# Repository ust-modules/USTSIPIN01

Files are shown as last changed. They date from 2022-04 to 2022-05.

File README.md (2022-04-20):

# USTSIPIN01A
It is intended for masurement of cosmic radiation and dosimetry by using Silicon PIN diode sensor.  

> USTSIPIN01A was originally named SPACEDOS01A_PCB01A

Top view on SPACEDOS01A_PCB01B

**The first prototype (without connection of PB0 with R12)**
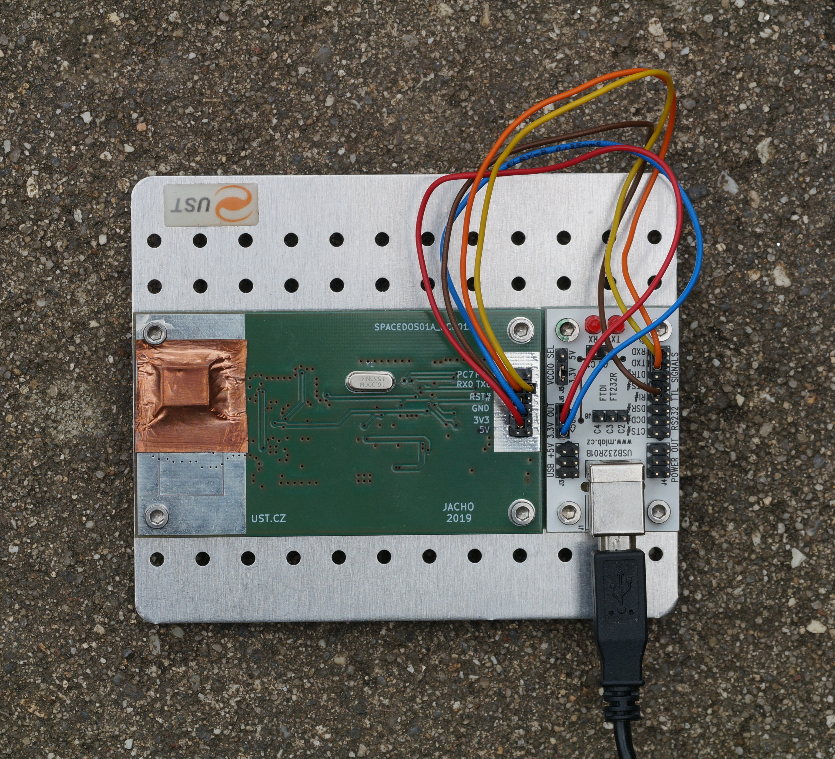
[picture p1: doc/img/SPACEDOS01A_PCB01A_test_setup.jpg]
USTSIPIN01A Test setup


### Technical parameters

* Silicon PIN diode detector with 12.5 mm³ detection volume
* Number of energy channels 250
* Deposited energy range from 200 keV to 12 MeV
* Energy measurement resolution < 50 keV/channel
* Power supply 3.3 V / 3 mA
* Integration time 15 s
* Interface - RS232 TTL
* H x W  x  L - 15mm x 51mm x 91mm

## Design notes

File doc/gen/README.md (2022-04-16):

# PCB

Board size: 90.93x50.29 mm (3.58x1.98 inches)

- This is the size of the rectangle that contains the board
- Thickness: 1.6 mm (63 mils)
- Material: FR4
- Finish: HAL
- Layers: 2
- Copper thickness: 35 µm

Solder mask: TOP / BOTTOM

- Color: Green

Silk screen: TOP / BOTTOM

- Color: White

# Important sizes

Clearance: 0.2 mm (8 mils)

Track width: 0.25 mm (10 mils)

- By design rules: 0.2 mm (8 mils)

Drill: 0.4 mm (16 mils)

- Vias: 0.4 mm (16 mils) [Design: 0.3 mm (12 mils)]
- Pads: 0.76 mm (30 mils)

Via: 0.8/0.4 mm (31/16 mils)

- By design rules: 0.8/0.3 mm (31/12 mils)
- Micro via: no [0.2/0.1 mm (8/4 mils)]
- Burried/blind via: no

Outer Annular Ring: 0.4 mm (16 mils)

- By design rules: 0.64 mm (25 mils)

Eurocircuits class: 4C

# General stats

Components count: (SMD/THT)

- Top: 2/14 (SMD + THT)
- Bottom: 87/8 (SMD + THT)

Defined tracks:

- 0.3 mm (12 mils)
- 0.4 mm (16 mils)
- 0.5 mm (20 mils)
- 0.6 mm (24 mils)
- 0.7 mm (28 mils)
- 0.8 mm (31 mils)

Used tracks:

- 0.25 mm (10 mils) (88) defined: no
- 0.3 mm (12 mils) (3) defined: yes
- 0.4 mm (16 mils) (328) defined: yes
- 0.6 mm (24 mils) (93) defined: yes
- 0.8 mm (31 mils) (60) defined: yes

Defined vias:

Used vias:

- 0.8/0.4 mm (31/16 mils) (Count: 223, Aspect: 2.0 A) defined: no

Holes (excluding vias):

- 0.76 mm (30 mils) (2)
- 0.8 mm (31 mils) (2)
- 0.89 mm (35 mils) (12)
- 3.0 mm (118 mils) (4)

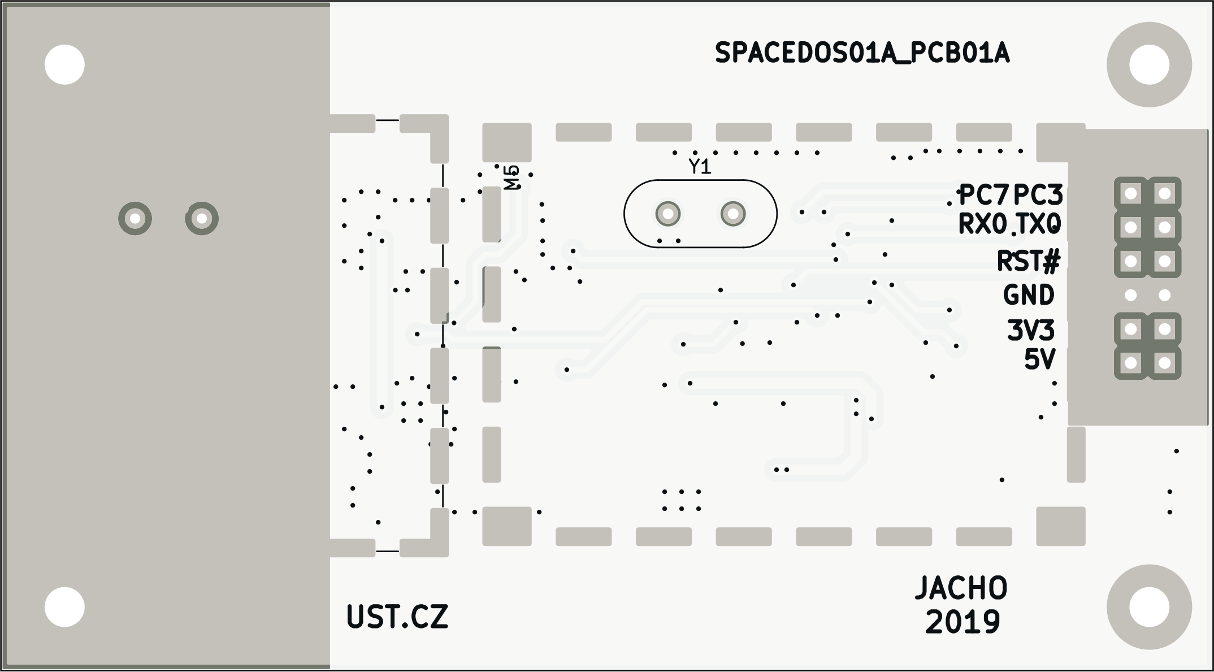
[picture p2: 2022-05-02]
doc/gen/img/USTSIPIN01-top.png

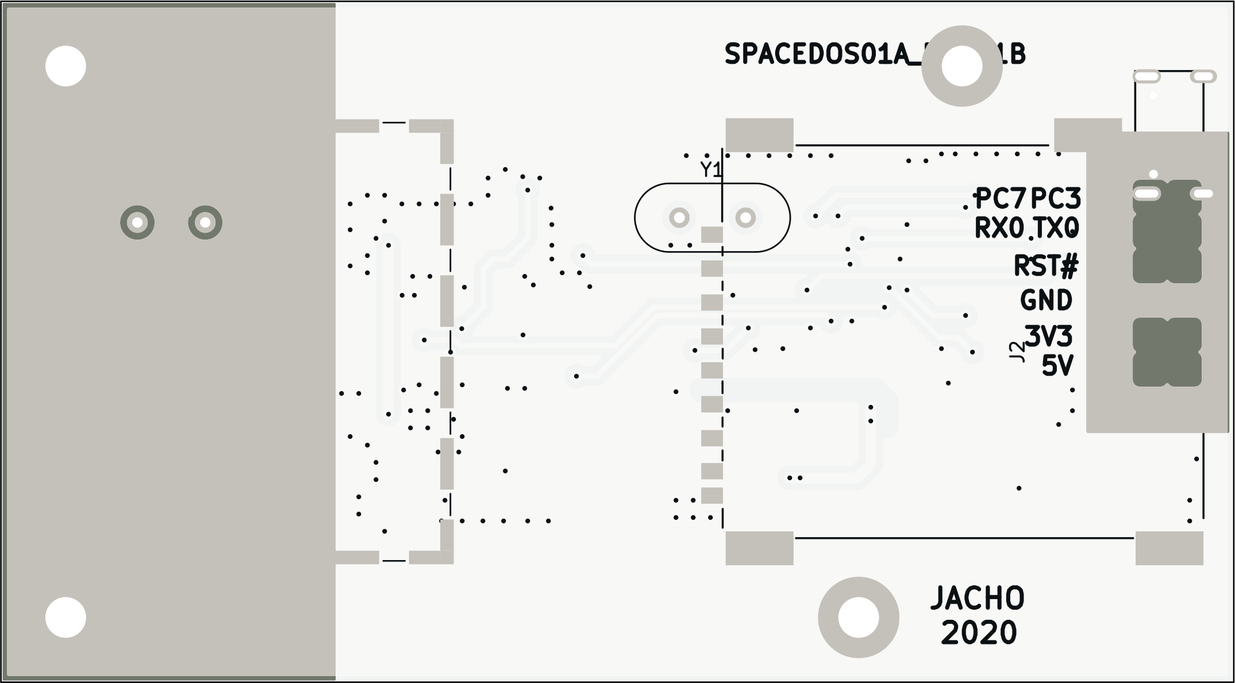
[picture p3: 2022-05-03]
doc/gen/img/USTSIPIN01A-top.png

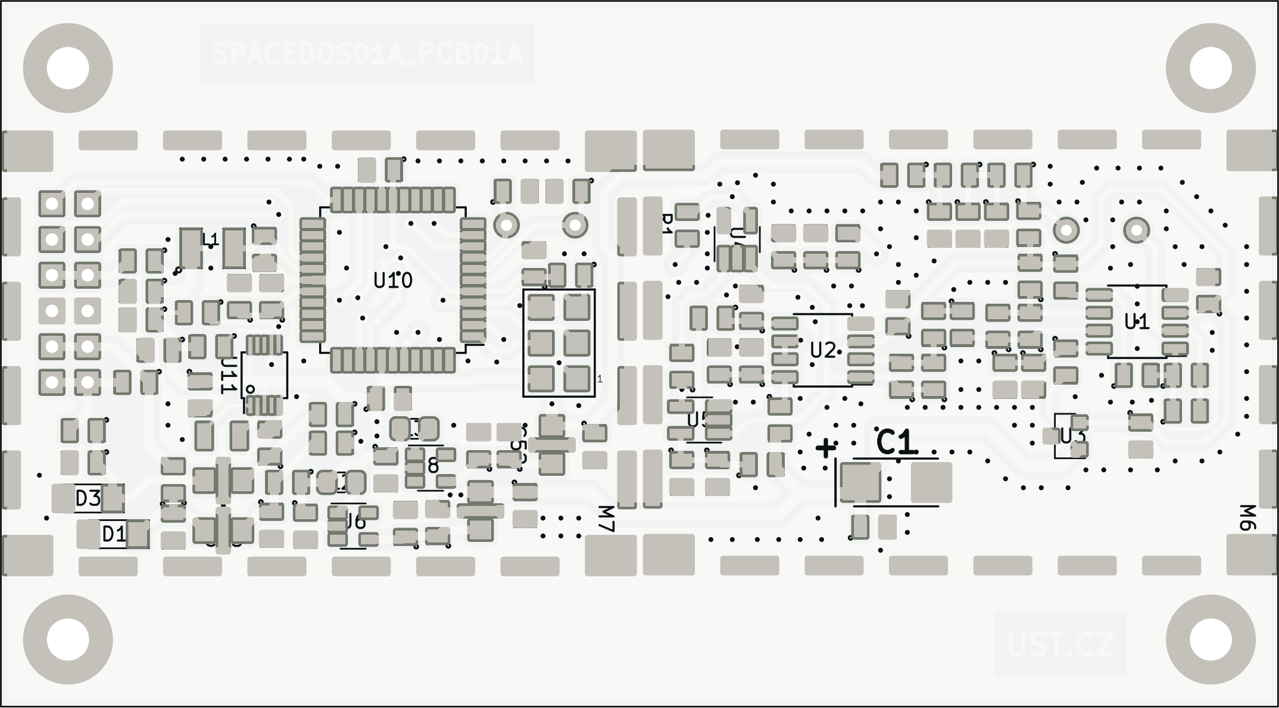
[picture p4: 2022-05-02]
doc/gen/img/USTSIPIN01-bottom.png

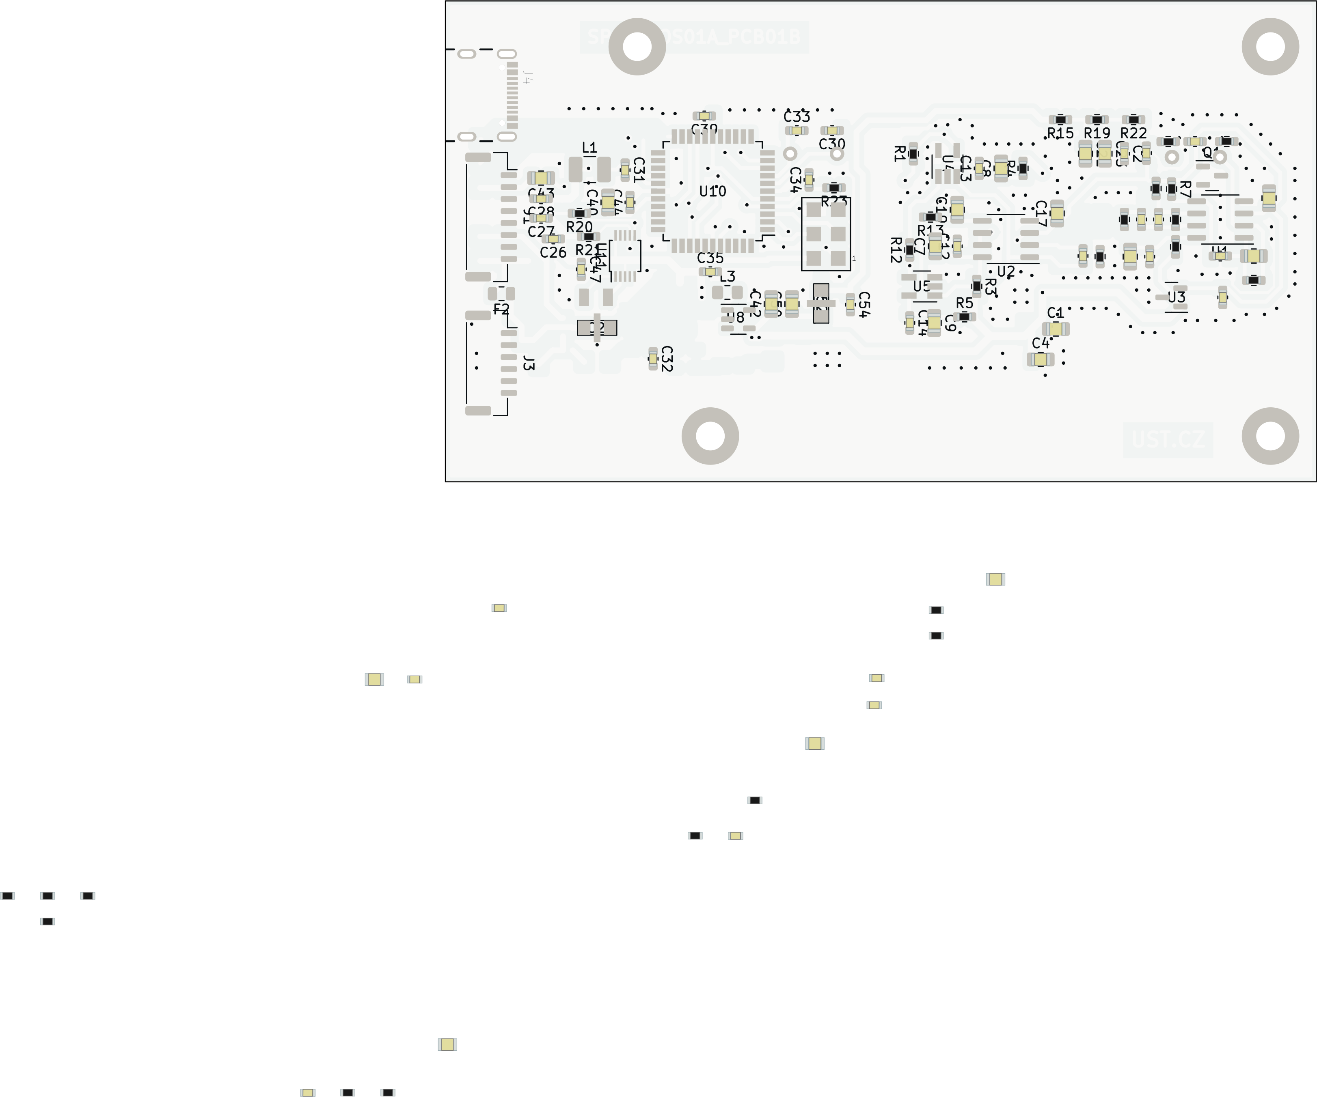
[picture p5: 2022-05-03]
doc/gen/img/USTSIPIN01A-bottom.png

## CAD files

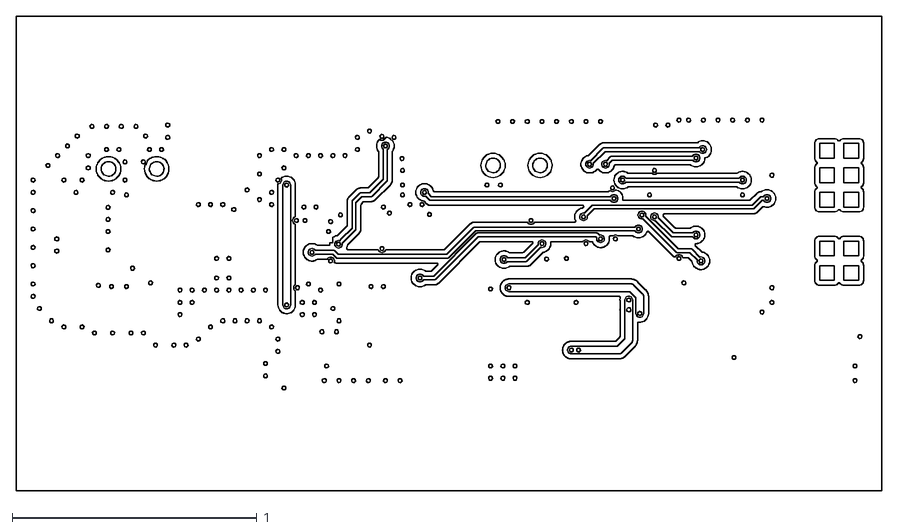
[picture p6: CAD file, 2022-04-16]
doc/gen/dxf/USTSIPIN01-F_Cu.dxf
3.54 x 1.94

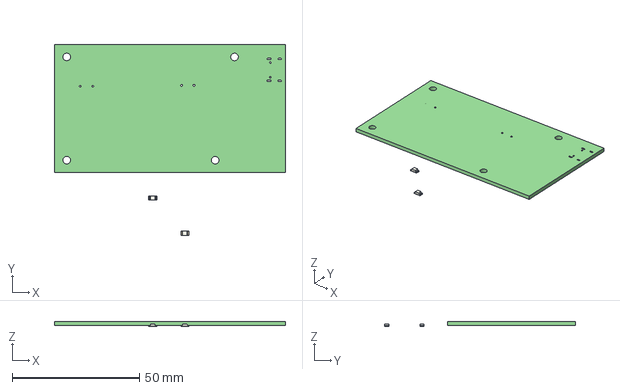
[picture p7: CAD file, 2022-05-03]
doc/gen/USTSIPIN01A.step
90.9 x 75.0 x 2.15 mm
tmpim7qj4tf PCB

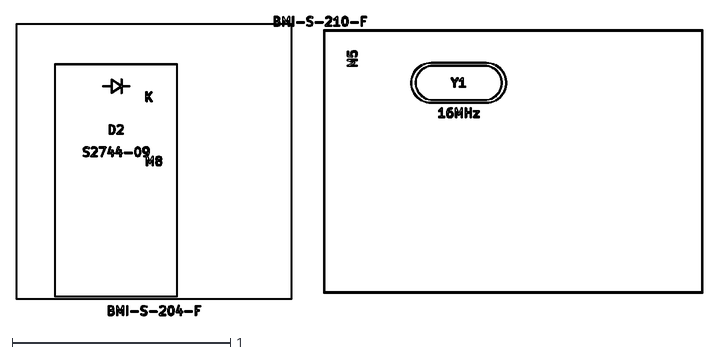
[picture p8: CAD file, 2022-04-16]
doc/gen/dxf/USTSIPIN01-F_Fab.dxf
3.15 x 1.37

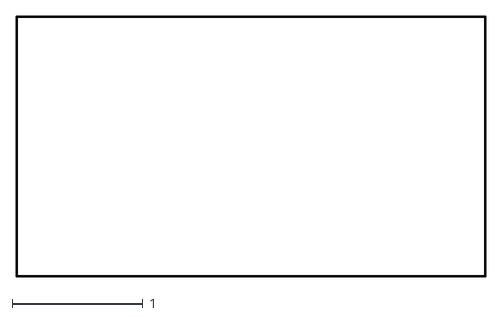
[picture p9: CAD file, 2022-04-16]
doc/gen/dxf/USTSIPIN01-Edge_Cuts.dxf
3.59 x 1.99

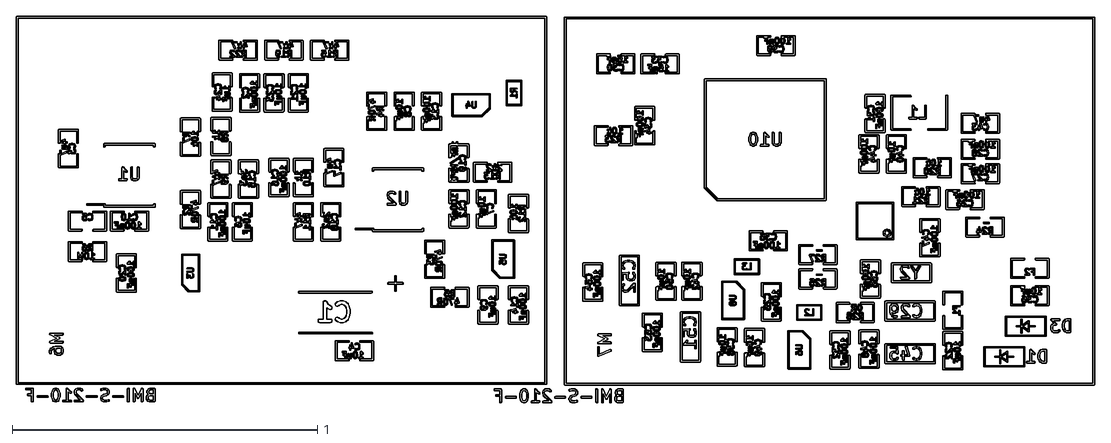
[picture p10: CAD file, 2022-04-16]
doc/gen/dxf/USTSIPIN01-B_Fab.dxf
3.53 x 1.27

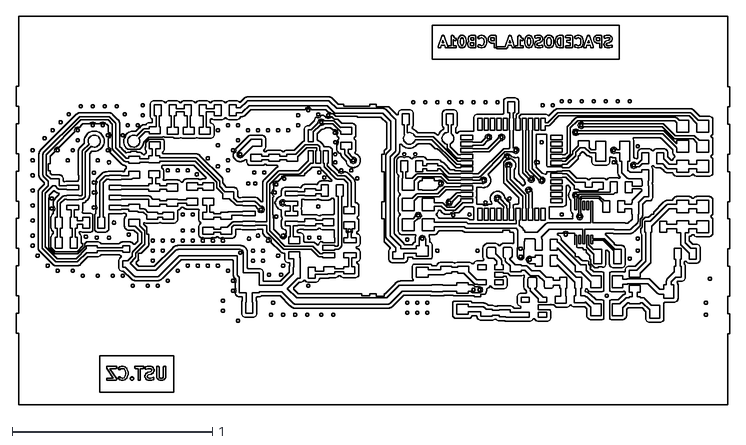
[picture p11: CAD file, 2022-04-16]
doc/gen/dxf/USTSIPIN01-B_Cu.dxf
3.56 x 1.94

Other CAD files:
doc/gen/dxf/USTSIPIN01-B_Mask.dxf
doc/gen/dxf/USTSIPIN01-B_Paste.dxf
doc/gen/dxf/USTSIPIN01-B_Silkscreen.dxf
doc/gen/dxf/USTSIPIN01-F_Mask.dxf
doc/gen/dxf/USTSIPIN01-F_Silkscreen.dxf

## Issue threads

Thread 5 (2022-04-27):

Označení konfigurace detektoru

roman-dvorak, 2022-04-27:
Detektor lze vyrobit ve více různých konfiguracích. Bylo by proto vhodné se dohodnout na nějakém jednotném konceptu značení těchto detektorů.

Jako jedna z variant, která mne napadá je, na desce vyhradit místo, na které se bude lepit vytištěný štítek (z tiskárny na štítky), kdy štítek ponese variabliní informace. Štítek by měl mít jednotný formát.

Informace štítku:
 - Sériové číslo, datum výroby
 - Rozsah energií #4
 - Kalibrace?

Vzhledem na místo na PCB a stinícím krabičkám:
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
By ideální místo bylo okolo hrany PCB, kde je 10 mm (existuje 9 mm široký štítek, znamenalo by to na silksceenu přesunout název modulu někam jinam) nebo přímo na stínící krabičku.

kaklik, 2022-05-03:
Pokud takový štítek bude v lidsky čitelném formátu, tak bude dost velký.  Nebylo by lepší na detektor lepit spíše něco jako seriové číslo a jeho parametry mít uloženy jinde? Například v nějaké databázi.
Stejný princip se už používá i u jiných snímačů viz https://en.wikipedia.org/wiki/IEEE_1451#Transducer_electronic_data_sheet

roman-dvorak, 2022-05-03:
Nemusí být tak velký, aby se to tam nevešlo. Záleží, co vše má být součástí. Mohou tam být poznamenány pouze základní údaje. Tj. třeba 3,4 hodnoty. Zbytek pak někde jinde dle výrobního čísla.

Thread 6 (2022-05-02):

Integrated USB

roman-dvorak, 2022-05-02:
Použitý MCU obsahuje dvě hardwarové UART rozhraní. Jedno rozhraní by se mohlo vyhradit pro USB, které by se používalo pro "přenosné" a "krátkodobé" aplikace, kdy by se zařízení připojovalo k uživatelskému počitači. USB by zároveň sloužilo pro nahrávání firmware pomocí [Obslužné aplikace](https://github.com/UniversalScientificTechnologies/SPACEDOS03/issues/4).

Druhá sériovka by byla užívána pro aplikace, kde by zařízení bylo umístěné někam, kde by byl cizí UART datalogger. Nebo pro aplikace, kde je potřeba data přenášet na větší vzdálenost. Zároveň by to umožňovalo moct změnit firmware/konfiguraci zařízení po USB bez rozpojování zařizení či demontáže.

Díky integraci USB by SPACEDOS03A se stal velmi kompaktním a odolným zařízením. Následně by se pro zařízení mohla vyvinout nějaká tištěná/frézovaná hliníková krabička.

Nepříjemností pro vyřešení tohoto kroku je, že nemáme vyrobený a otestovaný [RS232R02](https://github.com/mlab-modules/USB232R02) převodní, který by se do USTSIPINu mohl zaintegrovat. Zároveň by měl (z pohledu životnosti/odolnosti) nejhorší pouzdro z celého modulu. Převodník však existuje ve variantě [SSOP](https://ftdichip.com/wp-content/uploads/2021/10/DS_FT231X.pdf). Ani jedna varianta není v dnešní době snadno koupitelná.

Potřebné kroky:
- [ ] Ověřit, že vybraný převodník je vhodný
- [ ] Upravit návrh PCB
- [ ] Navrhnout vnější design produktu (krabička, potisk, ..)

kaklik, 2022-05-03:
Tohle issue by podle mého mělo být součástí https://github.com/UniversalScientificTechnologies/SPACEDOS03 nikoliv tohoto detektčního modulu.

roman-dvorak, 2022-05-03:
Nesouhlasím.

roman-dvorak, 2022-05-03:
Nesouhlasím, protože tohle issue řeši integraci přímo do PCB za účelem kompaktnosti a zvětšení user-experience. A ne jako další MLAB modul.

kaklik, 2022-05-03:
> Nesouhlasím, protože tohle issue řeši integraci přímo do PCB za účelem kompaktnosti a zvětšení user-experience. A ne jako další MLAB modul.

Ano, to jsem pochopil. Ale řeší to jako vlastnost toho výslednýho zařízení, Nikoliv jako vlastost detekční části (což bylo původně smyslem tohoto modulu a repozitáře)

roman-dvorak, 2022-05-03:
Má to smysl. Protože SPACEDOS03 může mít další specifika oproti USTSIPIN01. Ať už nějaký způsob montáže (tj. krabička) nebo to může být následně využito v nějakých dalších kompletních celcích, kam se to dá přidat jako submodul. S tím, že to bude mít vlastnost, že to například lze například programovat přes USB.

Já to moc nechápu už třeba jen z důvodu, že jsi mi tvrdil, že použitý procesor má jednu hardwarovou sériovku. A přišel jsem s tím, že by to mohlo mít jako rozhraní i USB. Takže to oproti té tvé původnů představě (s jedním vyvedeným UARTEM) to zůstává stále kompatibilní.

kaklik, 2022-05-03:
> Má to smysl. Protože SPACEDOS03 může mít další specifika oproti USTSIPIN01. Ať už nějaký způsob montáže (tj. krabička) nebo to může být následně využito v nějakých dalších kompletních celcích, kam se to dá přidat jako submodul. S tím, že to bude mít vlastnost, že to například lze například programovat přes USB.
>
> Já to moc nechápu už třeba jen z důvodu, že jsi mi tvrdil, že použitý procesor má jednu hardwarovou sériovku. A přišel jsem s tím, že by to mohlo mít jako rozhraní i USB. Takže to oproti té tvé původnů představě (s jedním vyvedeným UARTEM) to zůstává stále kompatibilní.

Myslel jsem si, že ta druhá seriovka se tam dělá softwarově. Nikoliv že na tom modulu bude pouze jen jedna seriová linka. Dvě tam jsou potřěba z toho důvodu, že je k tomu občas potřěba připojit GPS a zároveň mít připojený nějaký nadřazený logger. Netušil jsem že teď je to vyřešené tak, že i ta druhá UART linka je taky HW (a když to tak je, tak bych to nerad měnil).

roman-dvorak, 2022-05-03:
> Nebo mít zařízení (modul), které má vyvedenou jen čistou seriovku na kterou lze něco připojit bez nějakých dalších "překvapení".

Tak z toho důvodu k tomu také poskytujeme schémata. Aby to nebylo "překvapením" ale aby s tím člověk počital. A prostě to bral jako vlastnost tohoto zařizení, že tam bude 200k pullup.

Navíc druhá sériovka to bude stále splňovat.

> Netušil jsem že teď je to vyřešené tak, že i ta druhá UART linka je taky HW (a když to tak je, tak bych to nerad měnil).
Tak rušit jí rozhodně nechceme.

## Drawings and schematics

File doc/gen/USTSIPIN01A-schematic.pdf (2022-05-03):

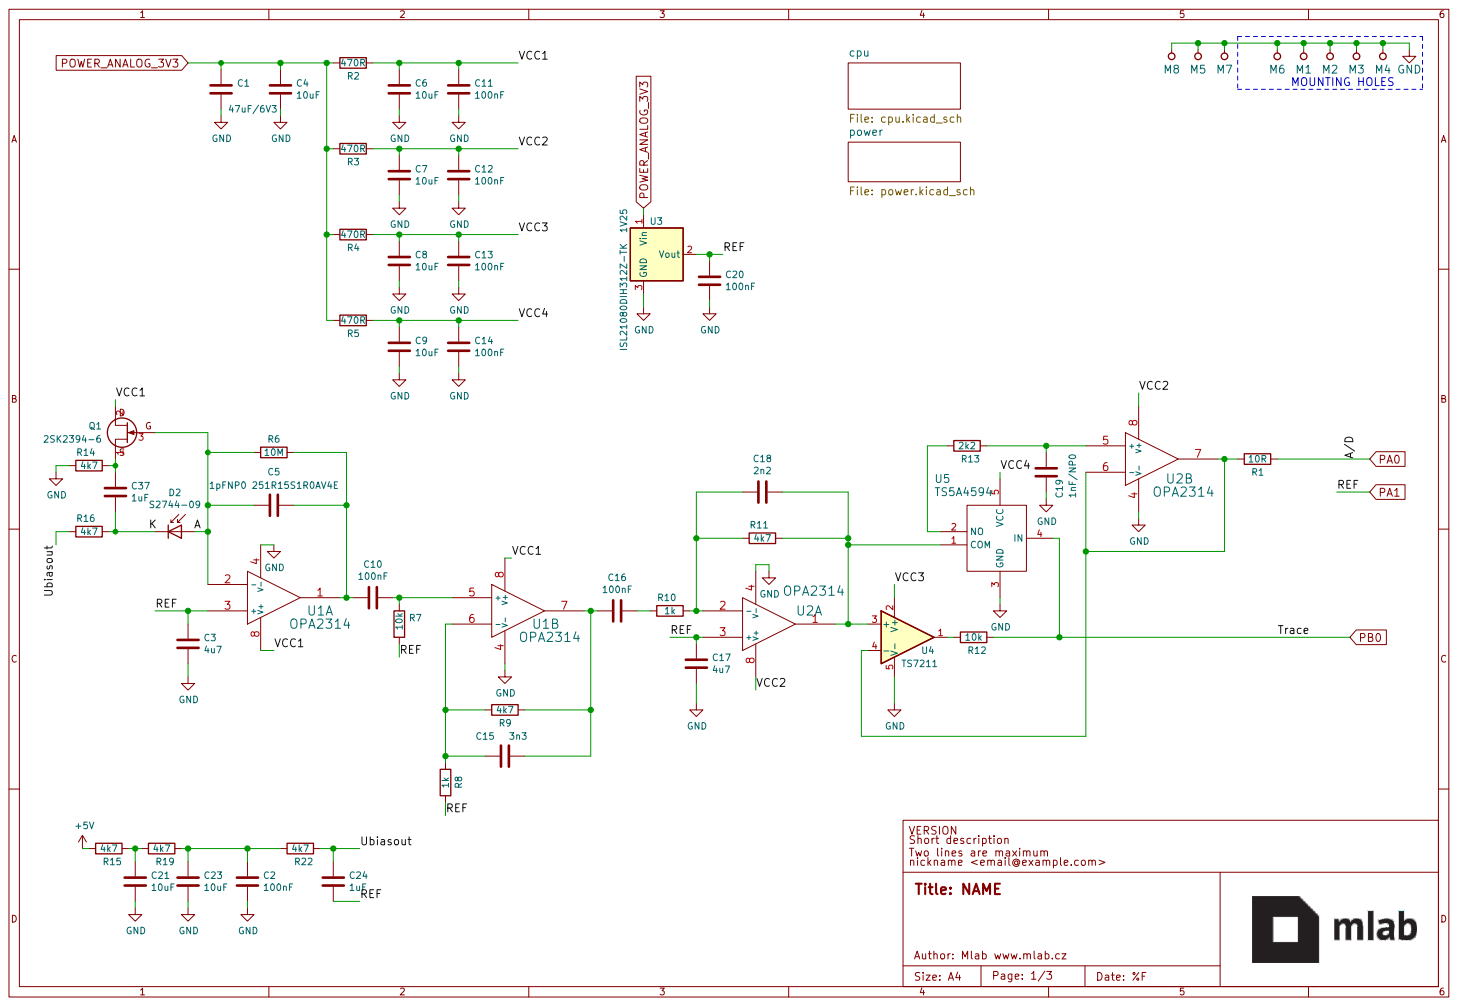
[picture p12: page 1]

VERSION
Short description
nickname <email@example.com>

Two lines are maximum

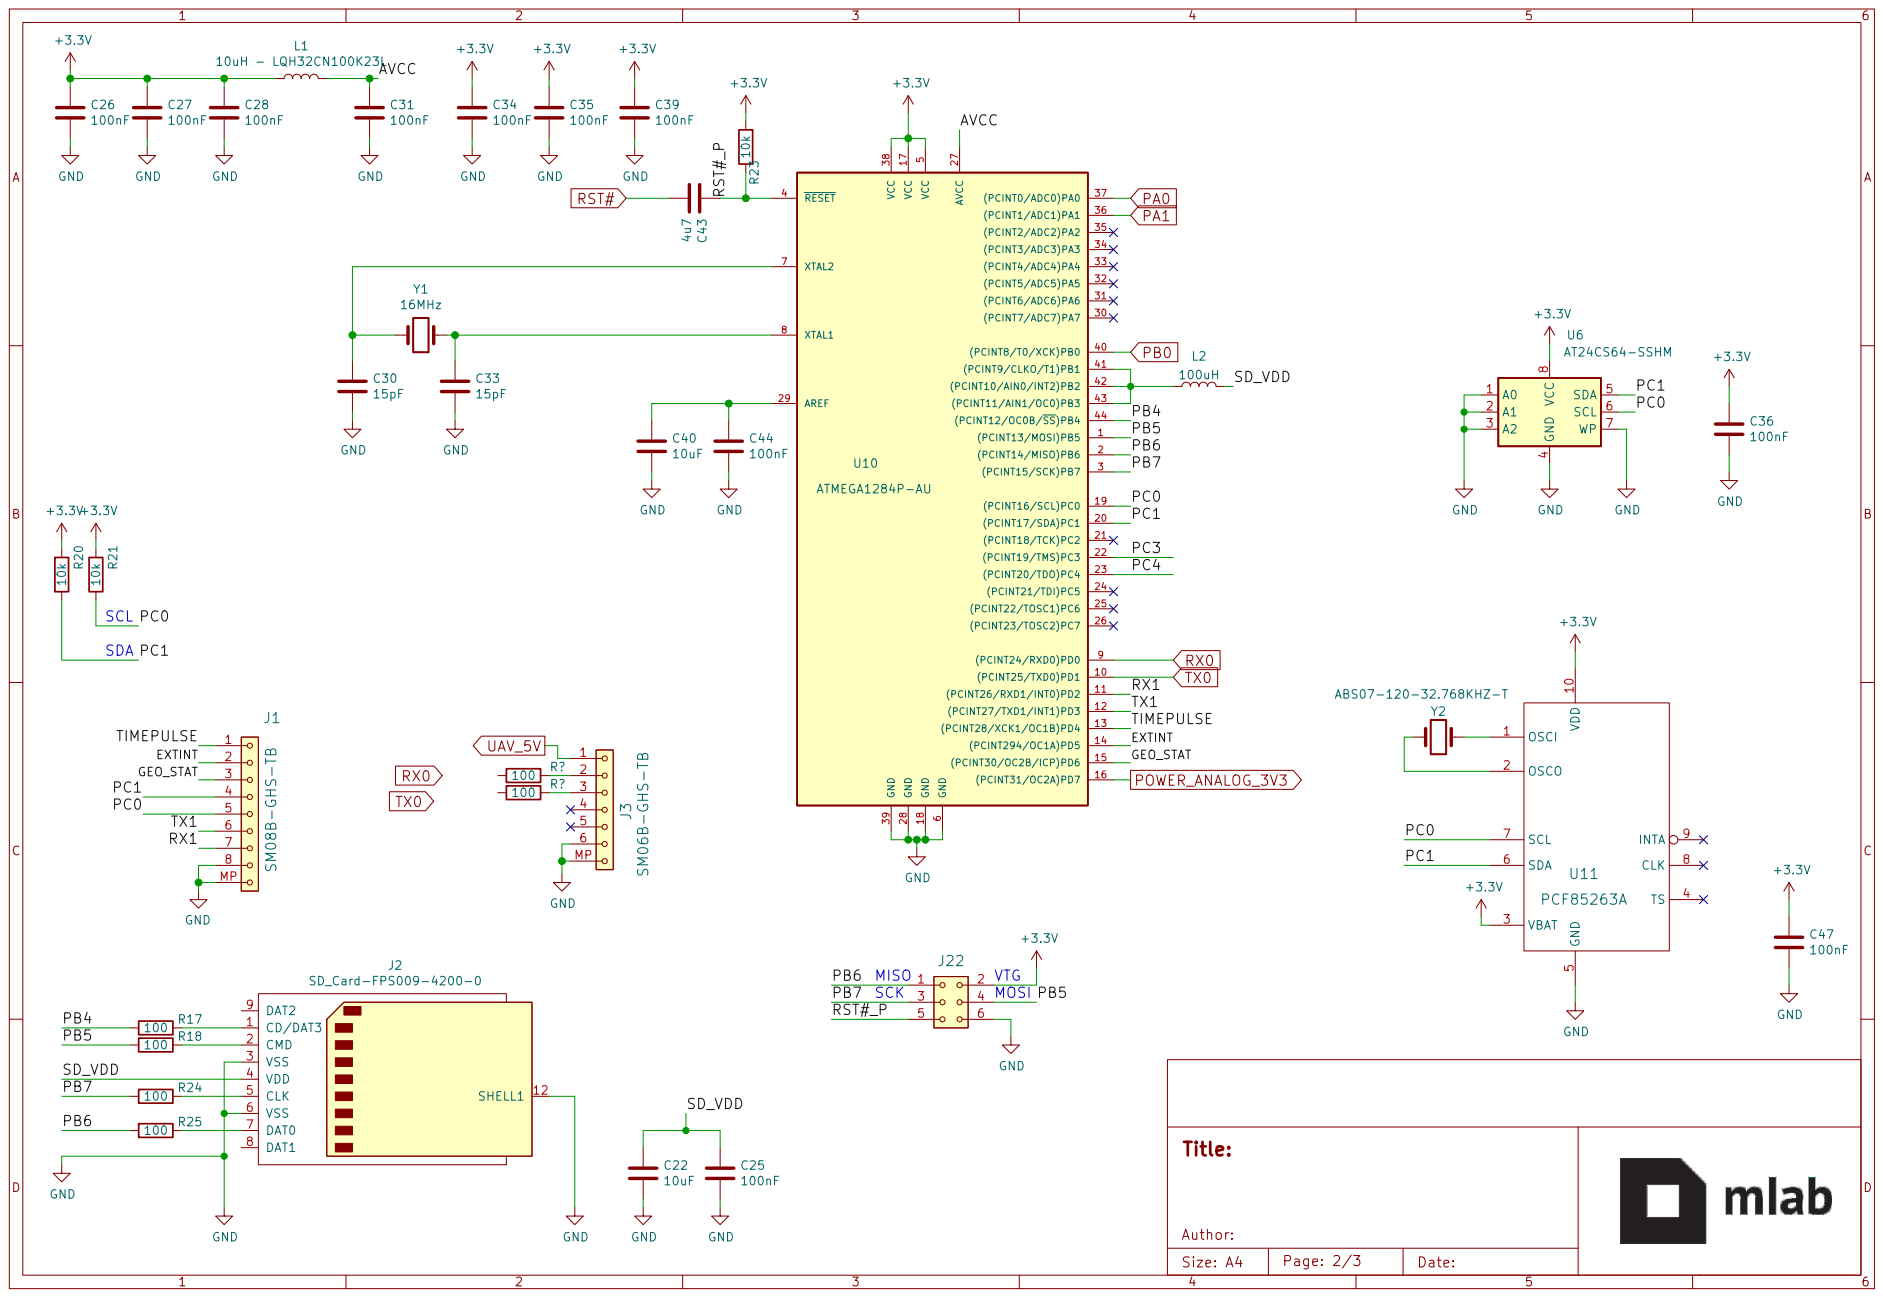
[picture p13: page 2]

4 SDA 5 SCL 6 WP 7 VCC

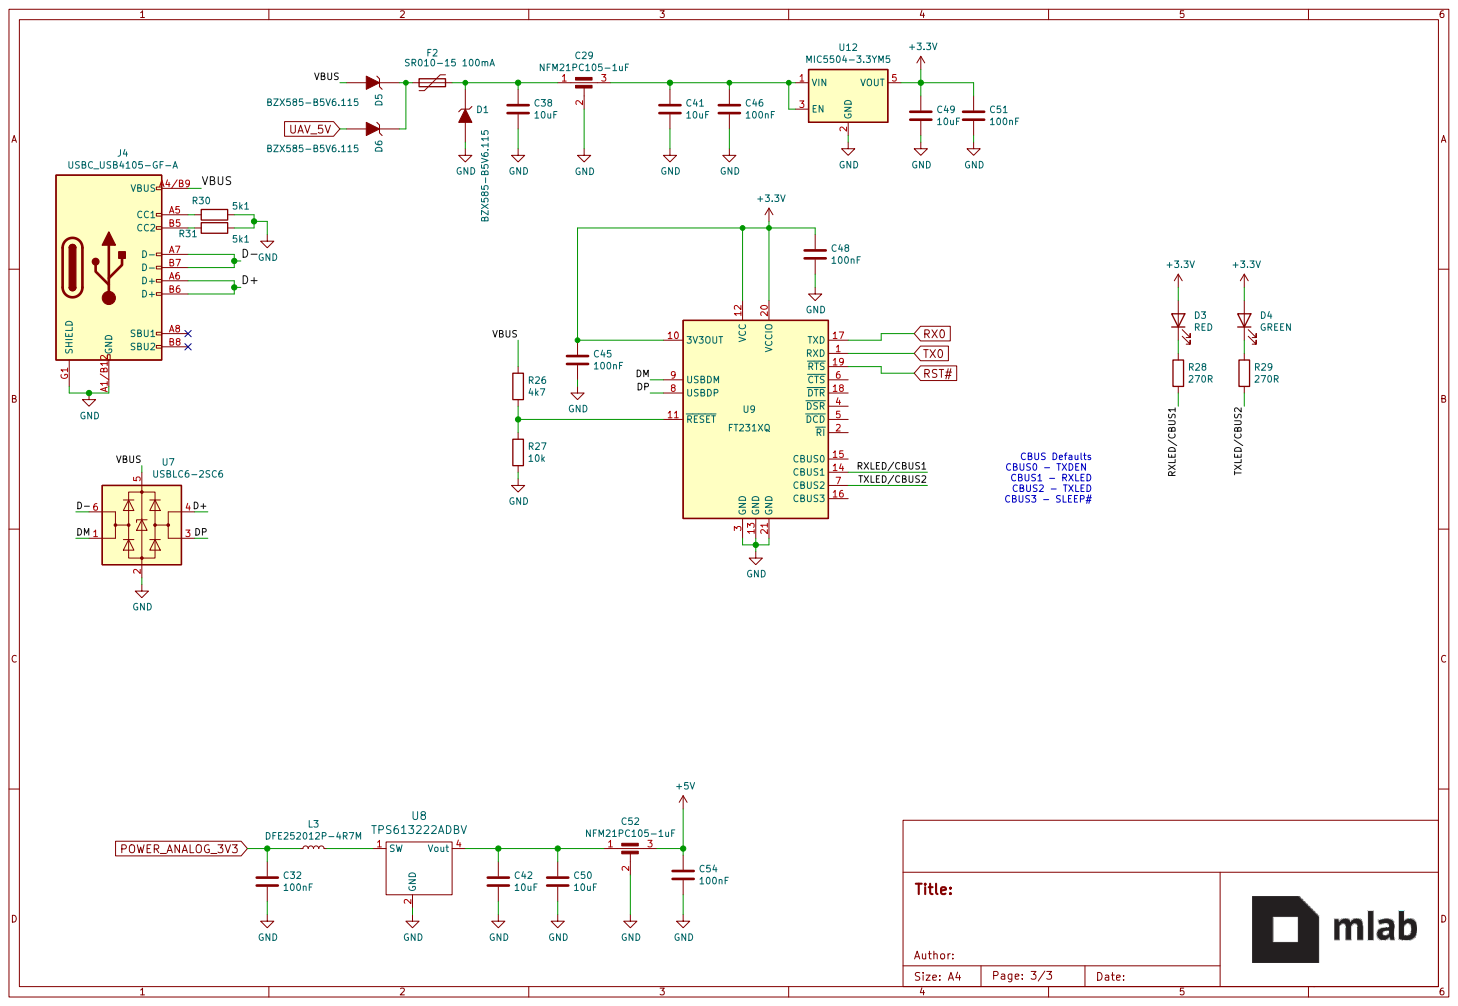
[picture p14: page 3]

3 ~{DSR} 4 ~{DCD} 5 ~{CTS} 6 CBUS2 7 USBDP 8 USBDM 9 U9 FT231XQ

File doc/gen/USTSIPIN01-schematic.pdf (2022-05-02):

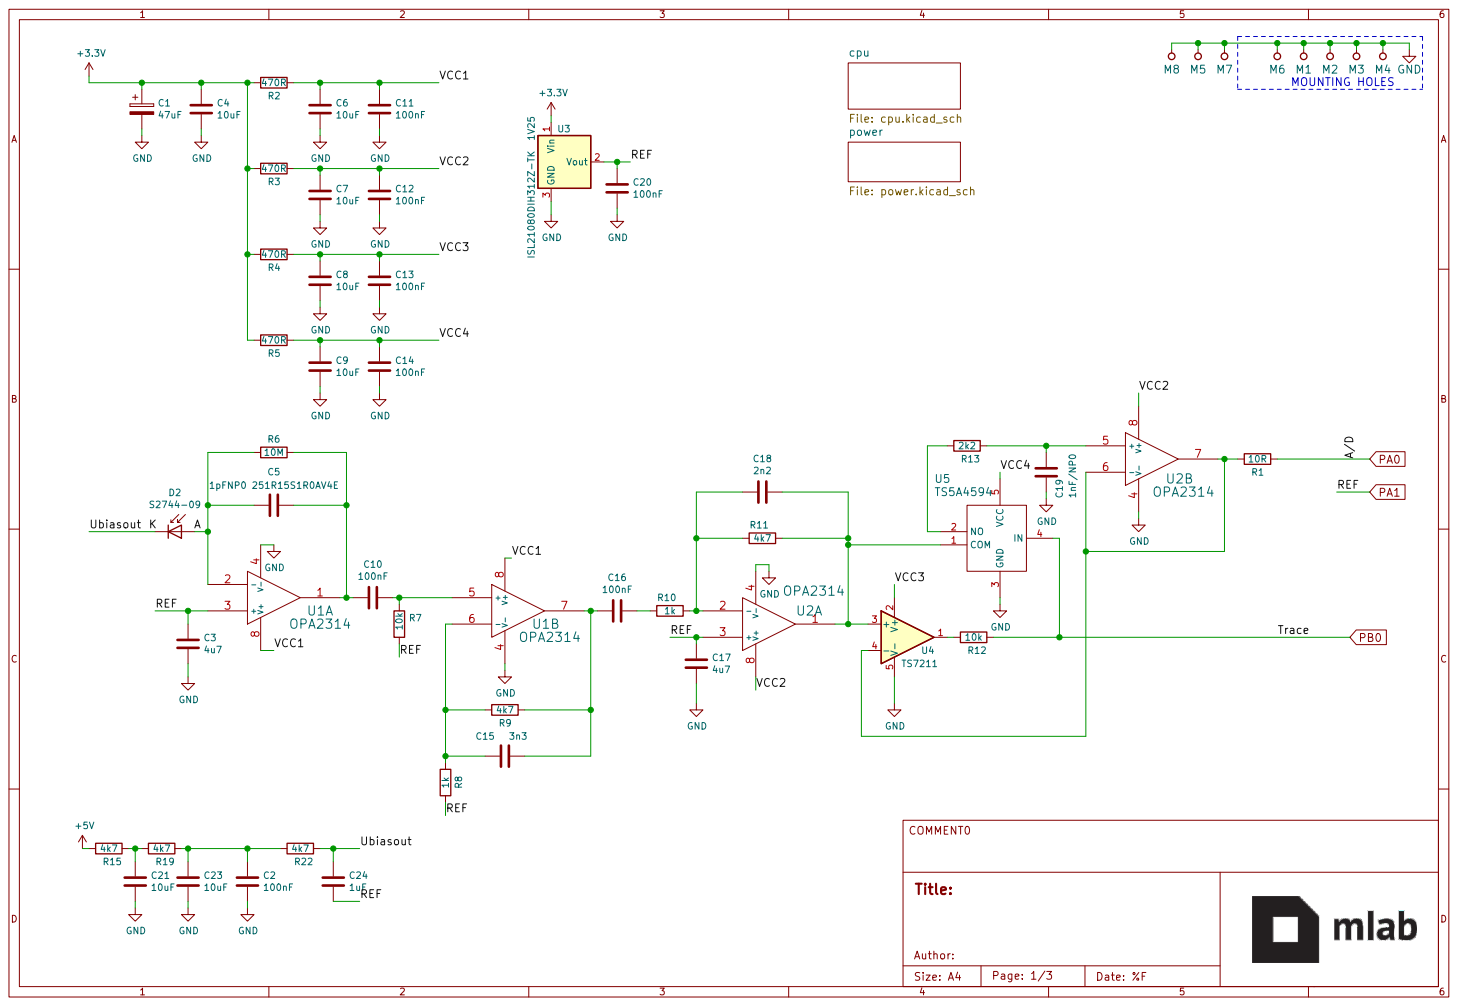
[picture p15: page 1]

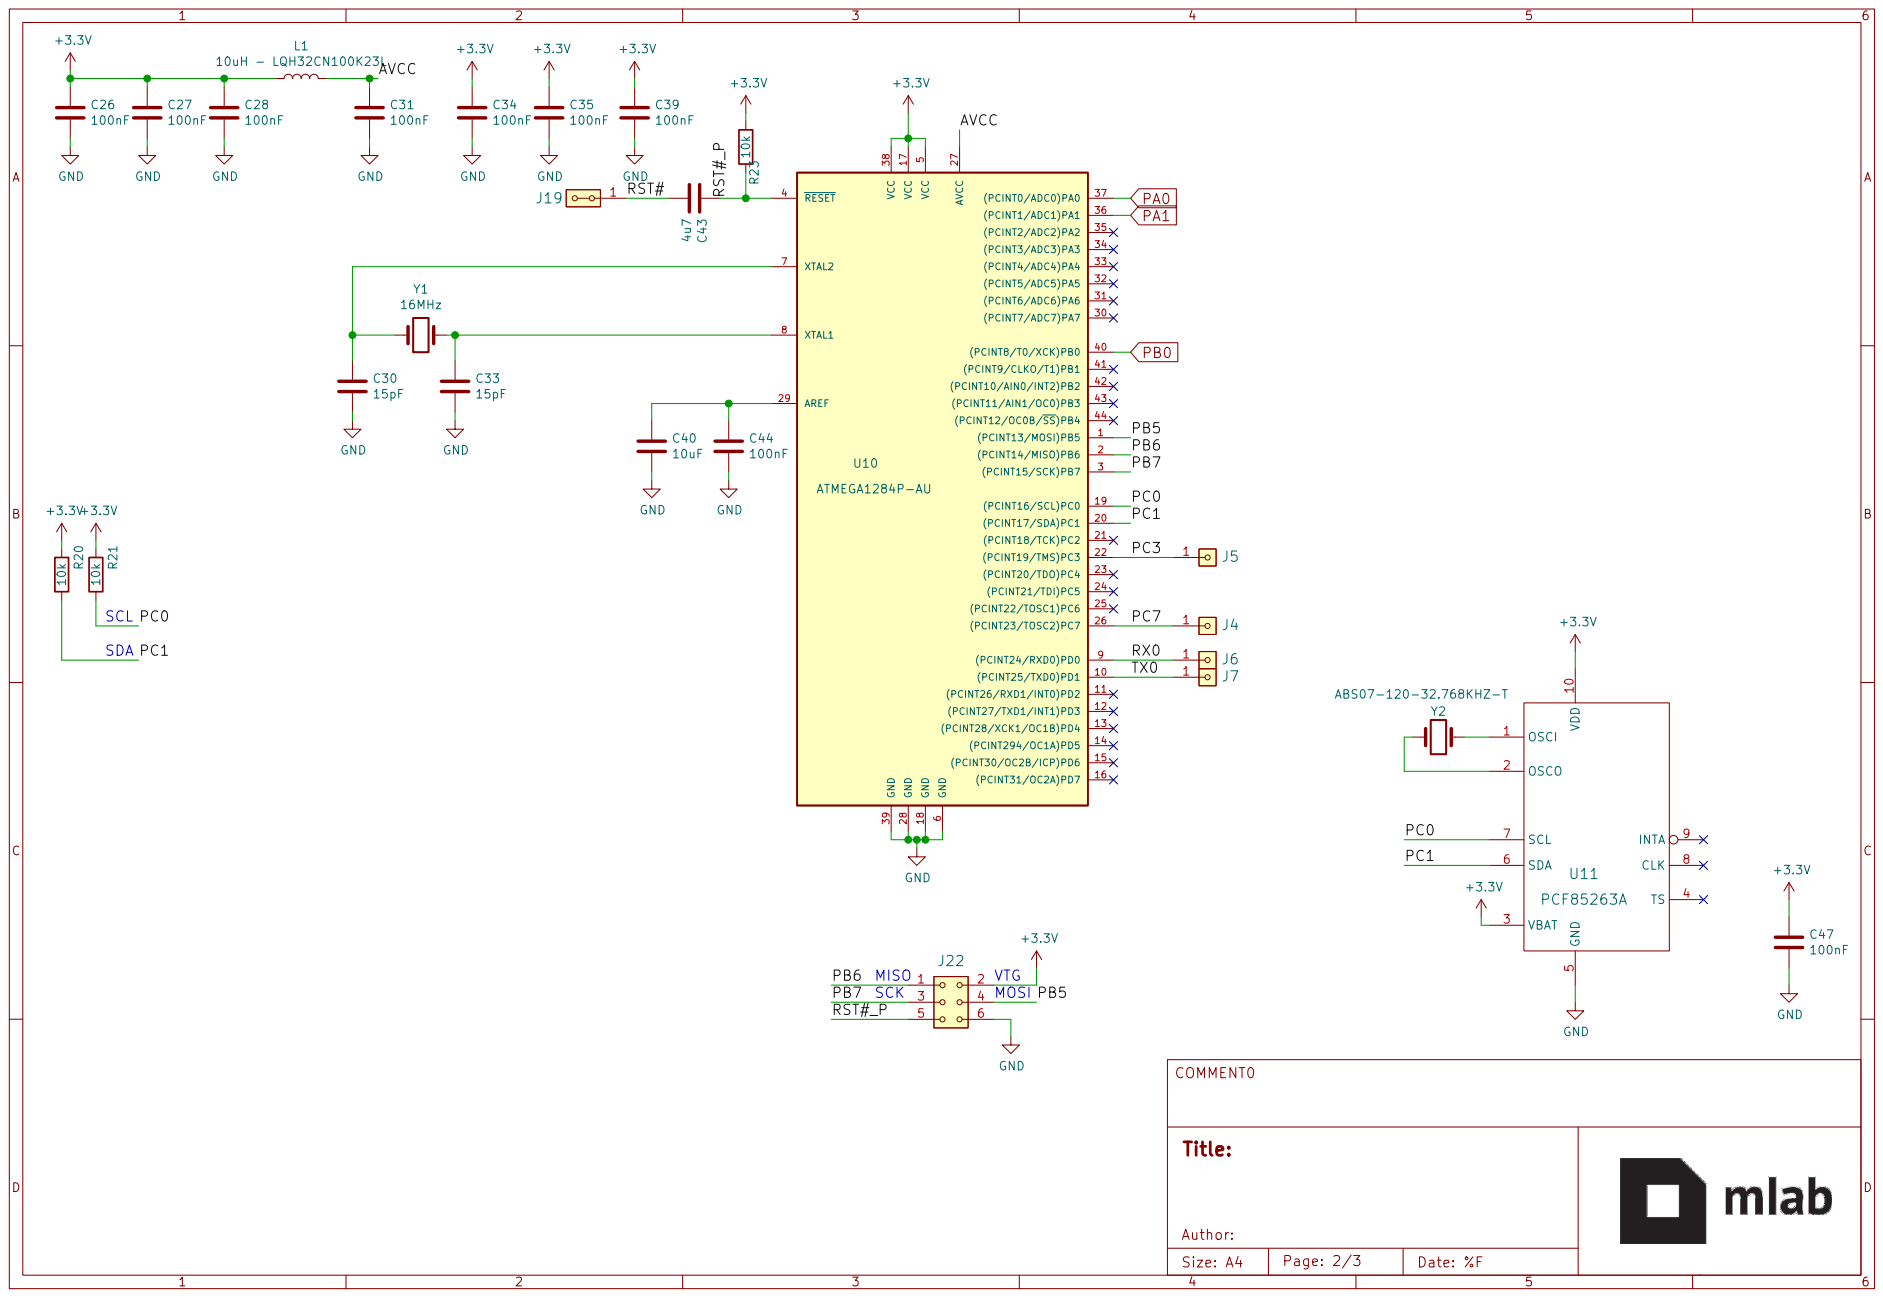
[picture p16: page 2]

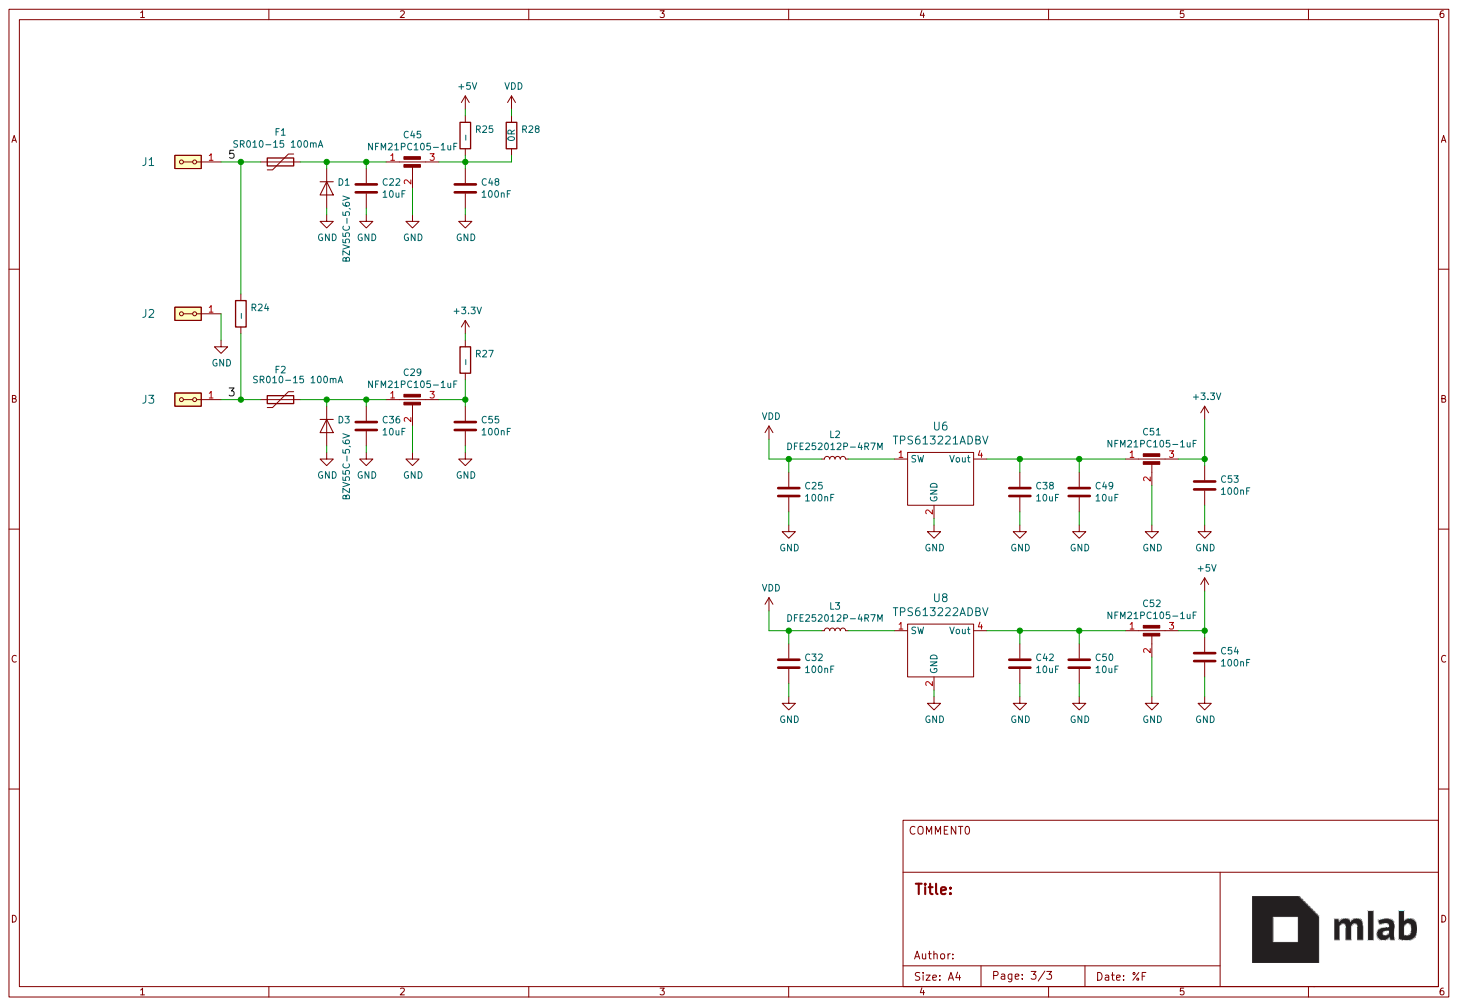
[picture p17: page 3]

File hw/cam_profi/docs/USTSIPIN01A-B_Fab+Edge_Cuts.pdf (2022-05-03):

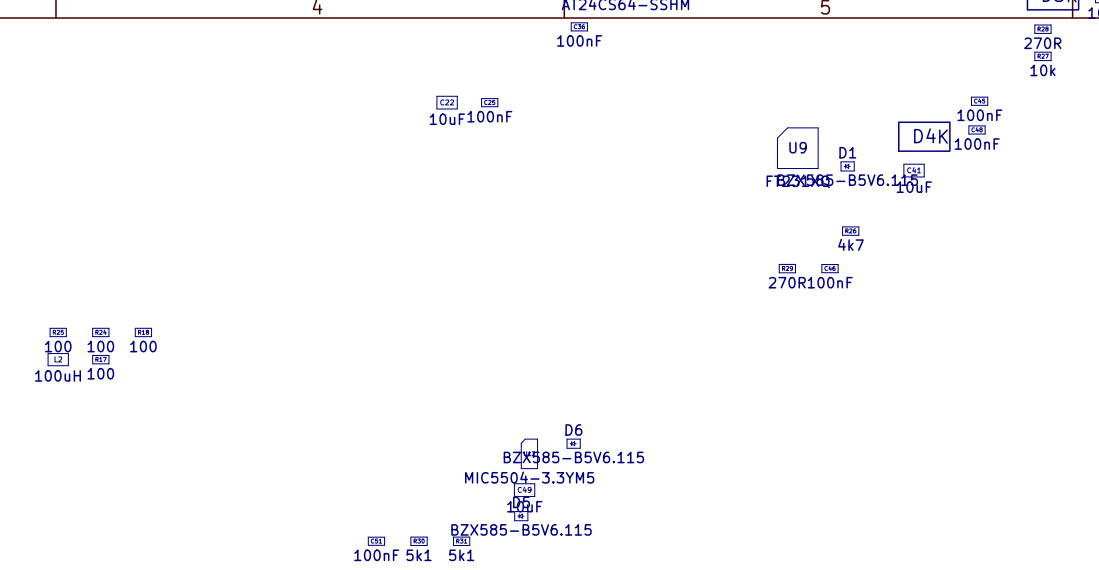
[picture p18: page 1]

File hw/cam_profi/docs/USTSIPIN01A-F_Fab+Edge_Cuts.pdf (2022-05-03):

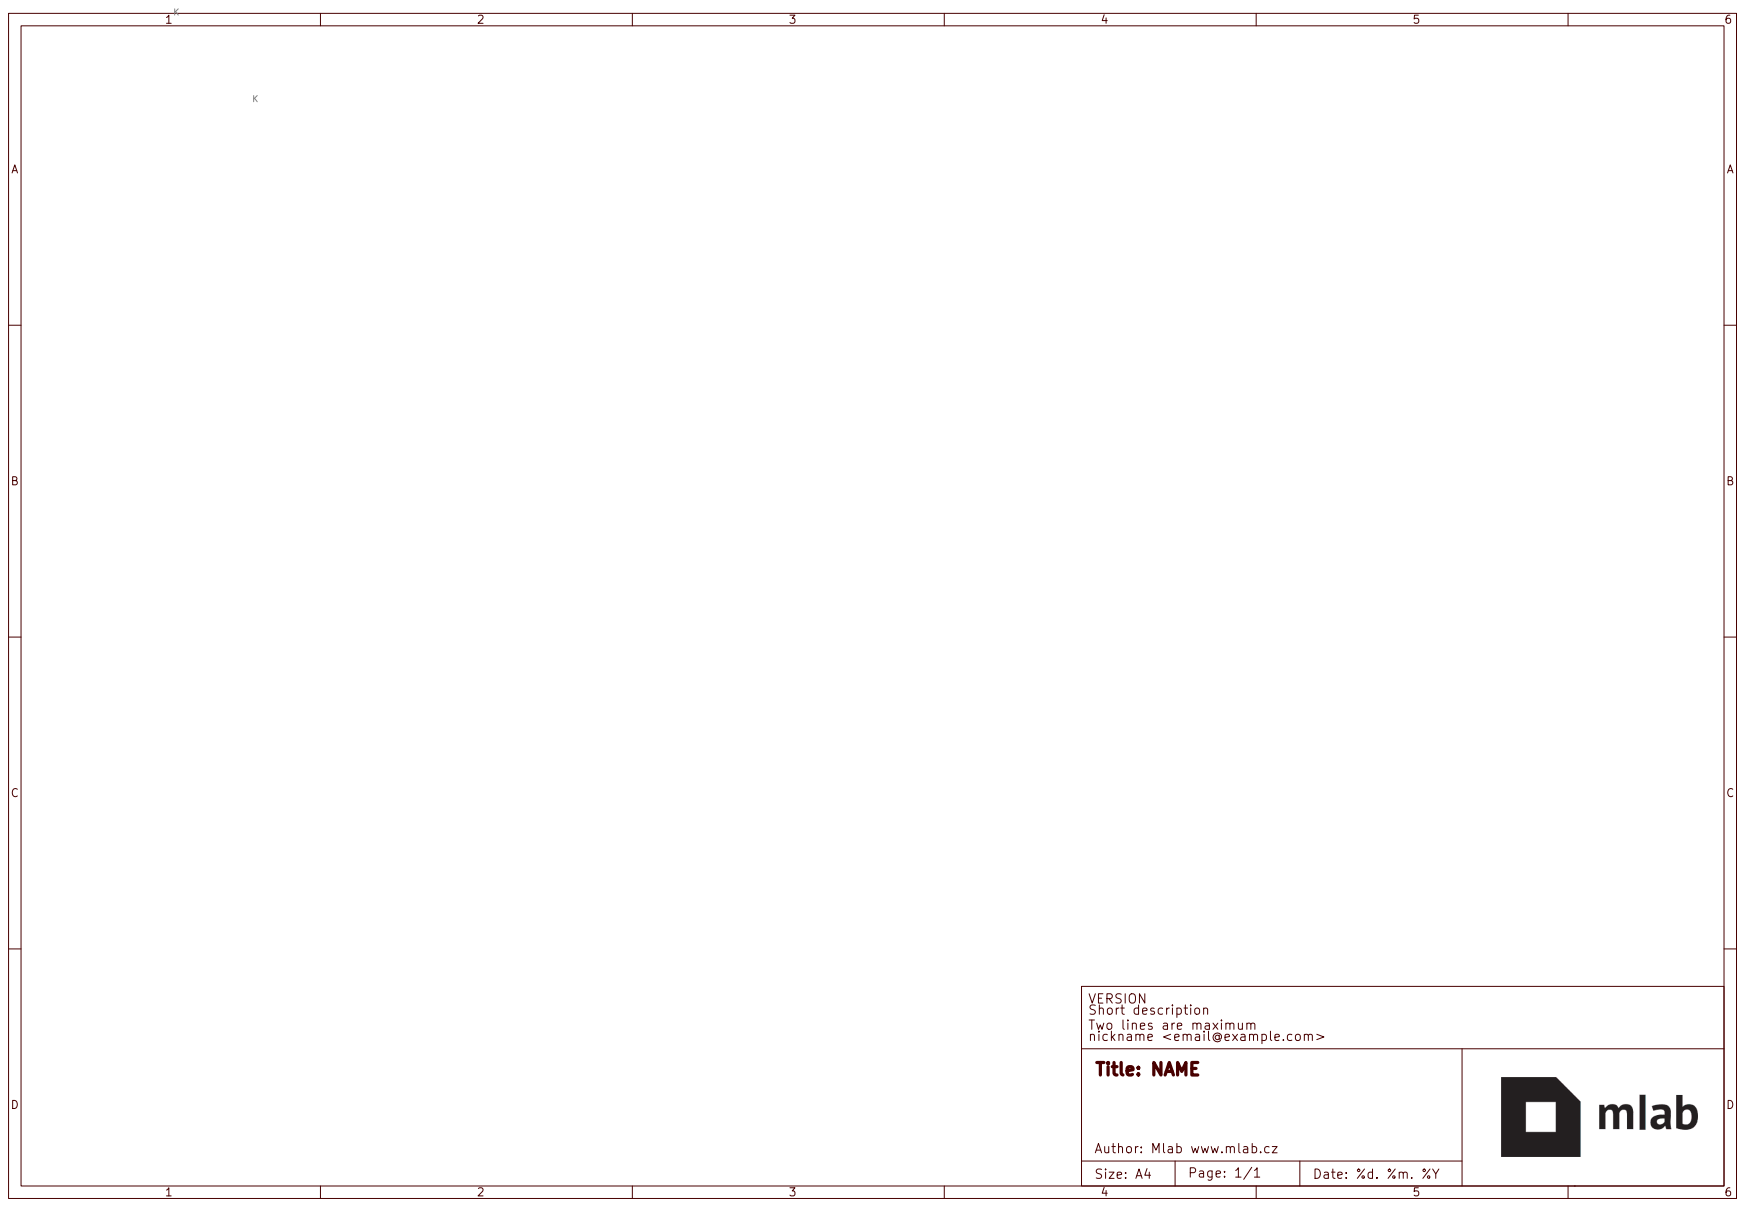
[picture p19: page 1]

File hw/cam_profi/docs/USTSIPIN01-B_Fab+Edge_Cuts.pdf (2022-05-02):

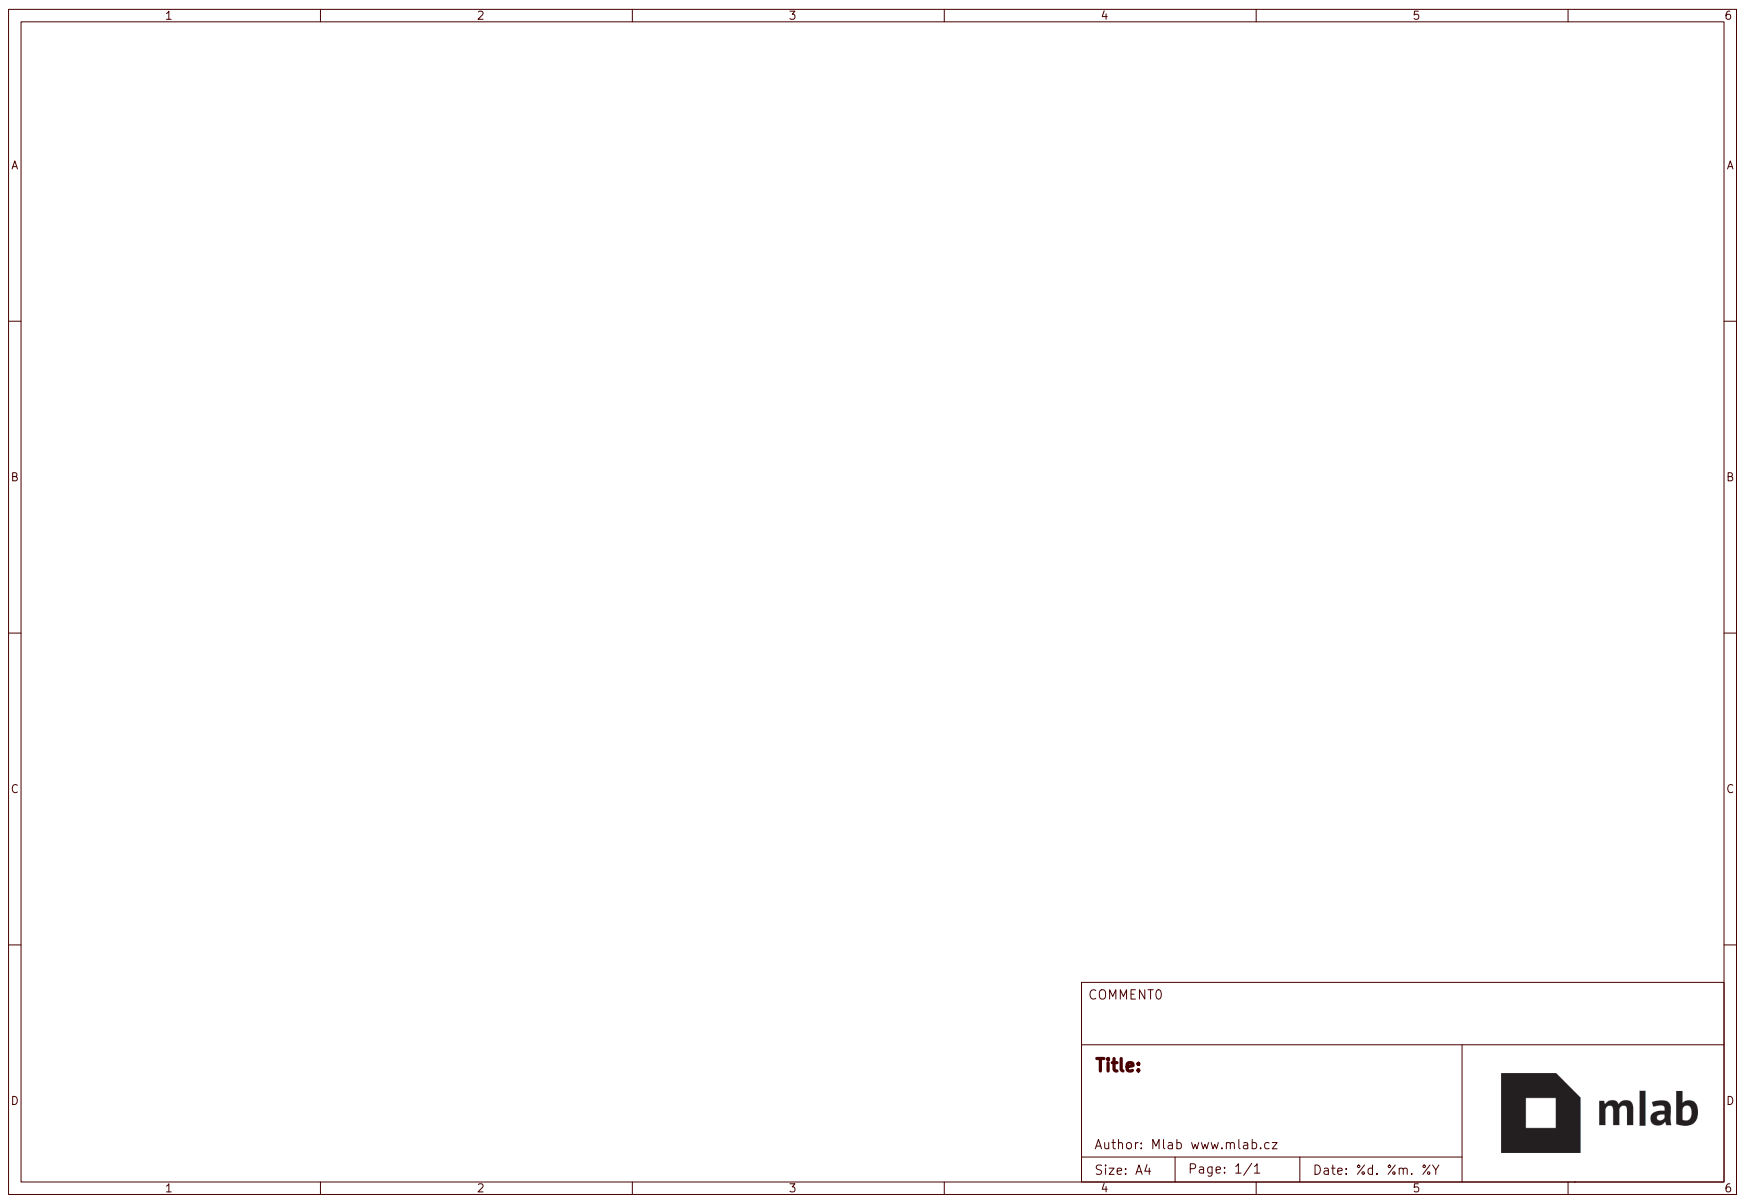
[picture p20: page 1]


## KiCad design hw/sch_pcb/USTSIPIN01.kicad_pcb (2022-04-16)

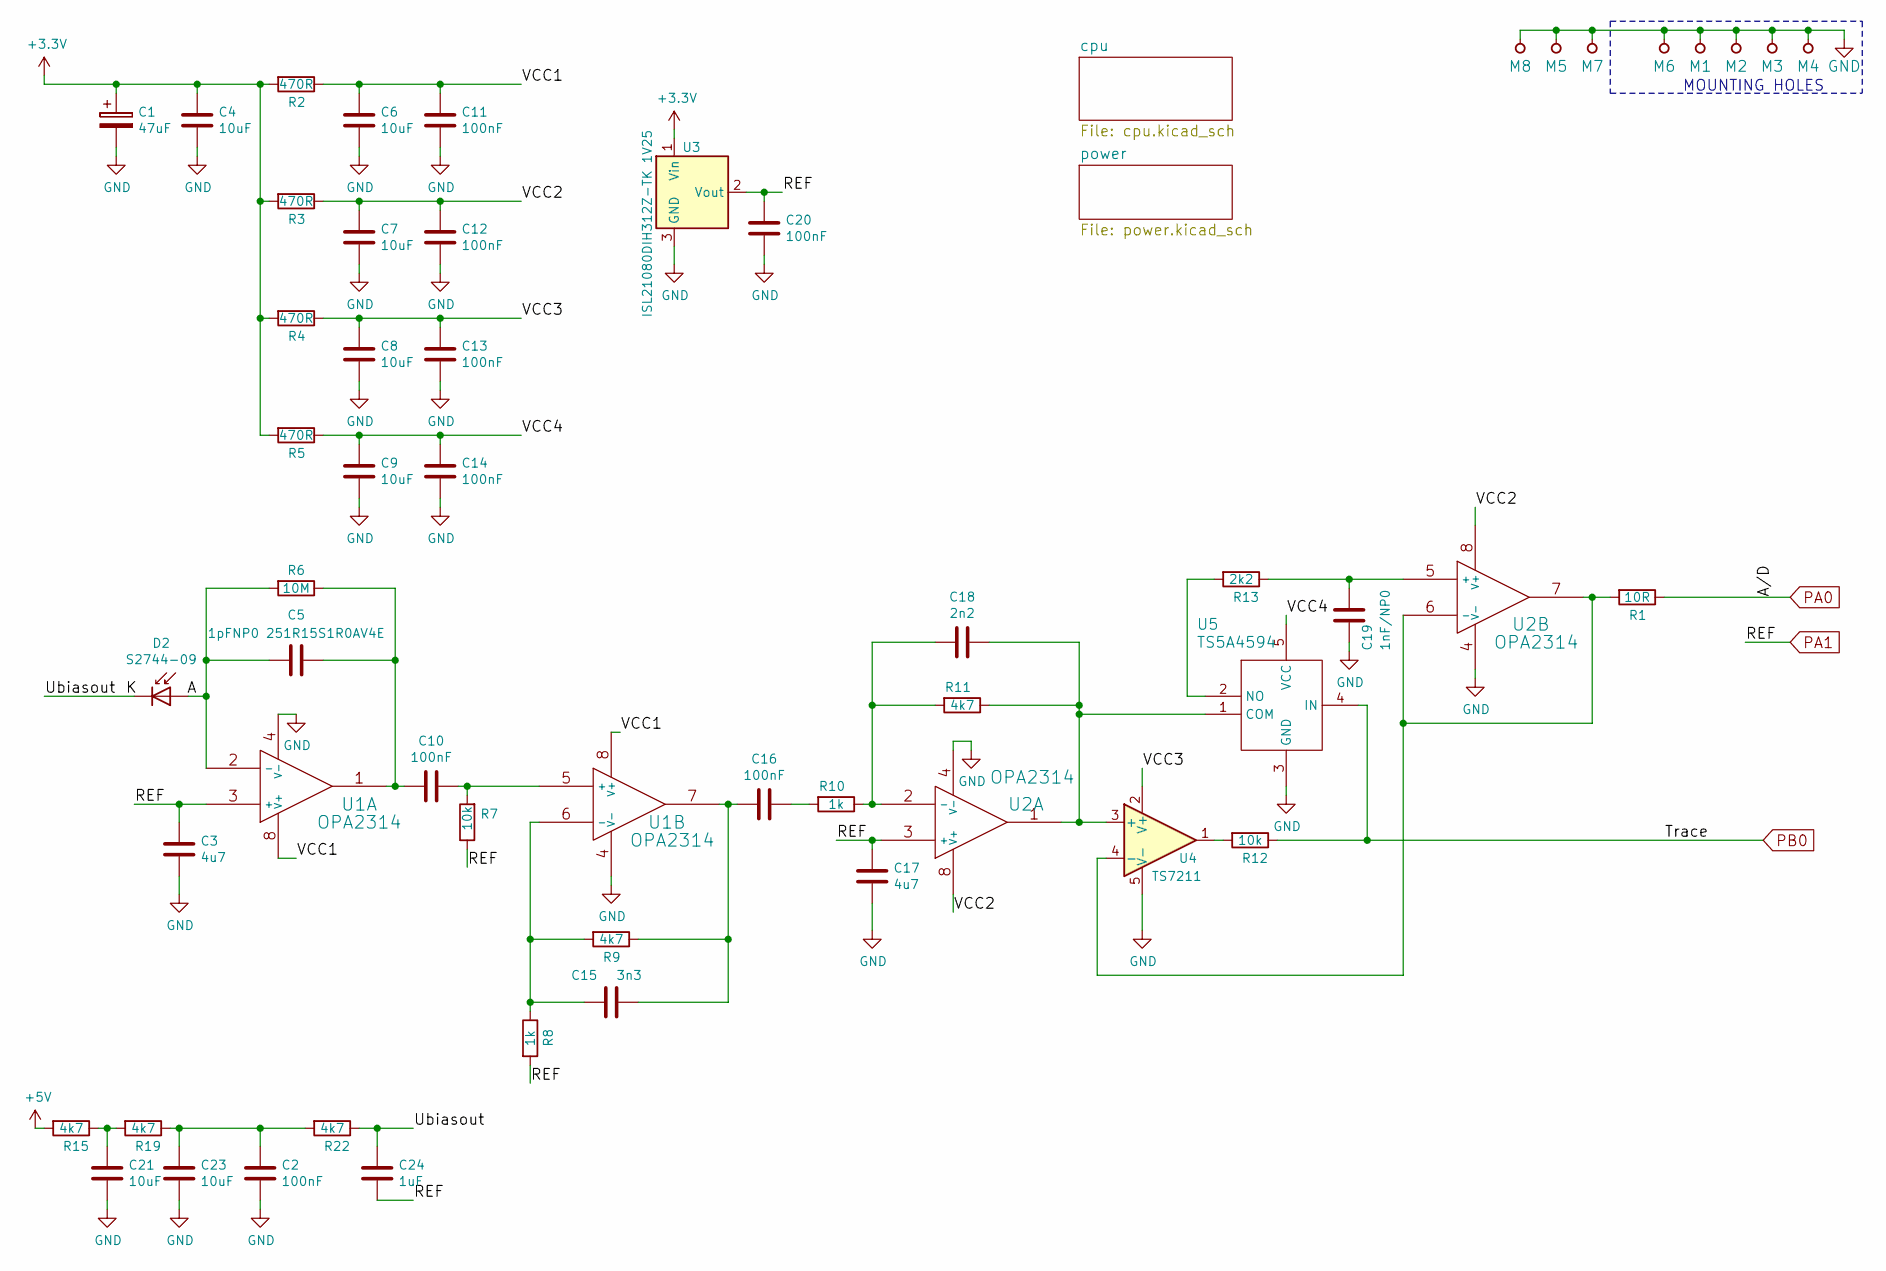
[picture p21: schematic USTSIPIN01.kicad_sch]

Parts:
C1: 47uF; TantalC_SizeC_Reflow
C2, C10, C11, C12, C13, C14, C16, C20: 100nF; SMD-0805
C3, C17: 4u7; SMD-0805
C4, C6, C7, C8, C9, C21, C23: 10uF; SMD-0805
C5: 1pFNP0 251R15S1R0AV4E; SMD-0805
C15: 3n3; SMD-0805
C18: 2n2; SMD-0805
C19: 1nF/NP0; SMD-0805
C24: 1uF; SMD-0805
D2: S2744-09; HAMAMATSU_S2744-09
M1, M2, M3, M4: HOLE; MountingHole_3mm
M5, M6, M7: BMI-S-210-F
M8: BMI-S-204-F; Laird_Technologies_BMI-S-204-F_32.00x32.00mm
R1: 10R; SMD-0805
R2, R3, R4, R5: 470R; SMD-0805
R6: 10M; SMD-0805
R7, R12: 10k; SMD-0805
R8, R10: 1k; SMD-0805
R9, R11, R15, R19, R22: 4k7; SMD-0805
R13: 2k2; SMD-0805
U1, U2: OPA2314; SOIC-8_3.9x4.9mm_Pitch1.27mm
U3: ISL21080DIH312Z-TK 1V25; SOT-23
U4: TS7211; SOT-23-5_HandSoldering
U5: TS5A4594; SOT-23-5_HandSoldering

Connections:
+3V3: C1.1, C4.1, R2.2, R3.2, R4.2, R5.2, U3.1 (Vin); also elsewhere on the board
+5V: R15.2; also elsewhere on the board
/A: C5.2, D2.2 (A), R6.2, U1.2 (-)
/K: C24.1, D2.1 (K), R22.1
/VCC1: C6.1, C11.1, R2.1, U1.8 (V+)
/VCC2: C7.1, C12.1, R3.1, U2.8 (V+)
/VCC3: C8.1, C13.1, R4.1, U4.2 (V+)
/VCC4: C9.1, C14.1, R5.1, U5.5 (VCC)
GND: C1.2, C2.2, C3.2, C4.2, C6.2, C7.2, C8.2, C9.2, C11.2, C12.2, C13.2, C14.2, C17.2, C19.2, C20.2, C21.2, C23.2, M1.1, M2.1, M3.1, M4.1, M5.1, M6.1, M7.1, M8.1, U1.4 (V-), U2.4 (V-), U3.3 (GND), U4.5 (V-), U5.3 (GND); also elsewhere on the board
unnamed: C2.1, C23.1, R19.1, R22.2
unnamed: C10.1, R7.2, U1.5 (+)
unnamed: C5.1, C10.2, R6.1, U1.1
unnamed: C15.1, C16.2, R9.1, U1.7
unnamed: C15.2, R8.1, R9.2, U1.6 (-)
unnamed: C16.1, R10.2
unnamed: C18.1, R11.1, U2.1, U4.3 (+), U5.1 (COM)
unnamed: C18.2, R10.1, R11.2, U2.2 (-)
unnamed: C19.1, R13.1, U2.5 (+)
unnamed: C21.1, R15.1, R19.2
unnamed: R1.2, U2.6 (-), U2.7, U4.4 (-)
unnamed: R12.2, U4.1
unnamed: R13.2, U5.2 (NO)
PA0: R1.1; also elsewhere on the board
PA1: C3.1, C17.1, C20.1, C24.2, R7.1, R8.2, U1.3 (+), U2.3 (+), U3.2 (Vout); also elsewhere on the board
PB0: R12.1, U5.4 (IN); also elsewhere on the board

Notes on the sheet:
MOUNTING HOLES

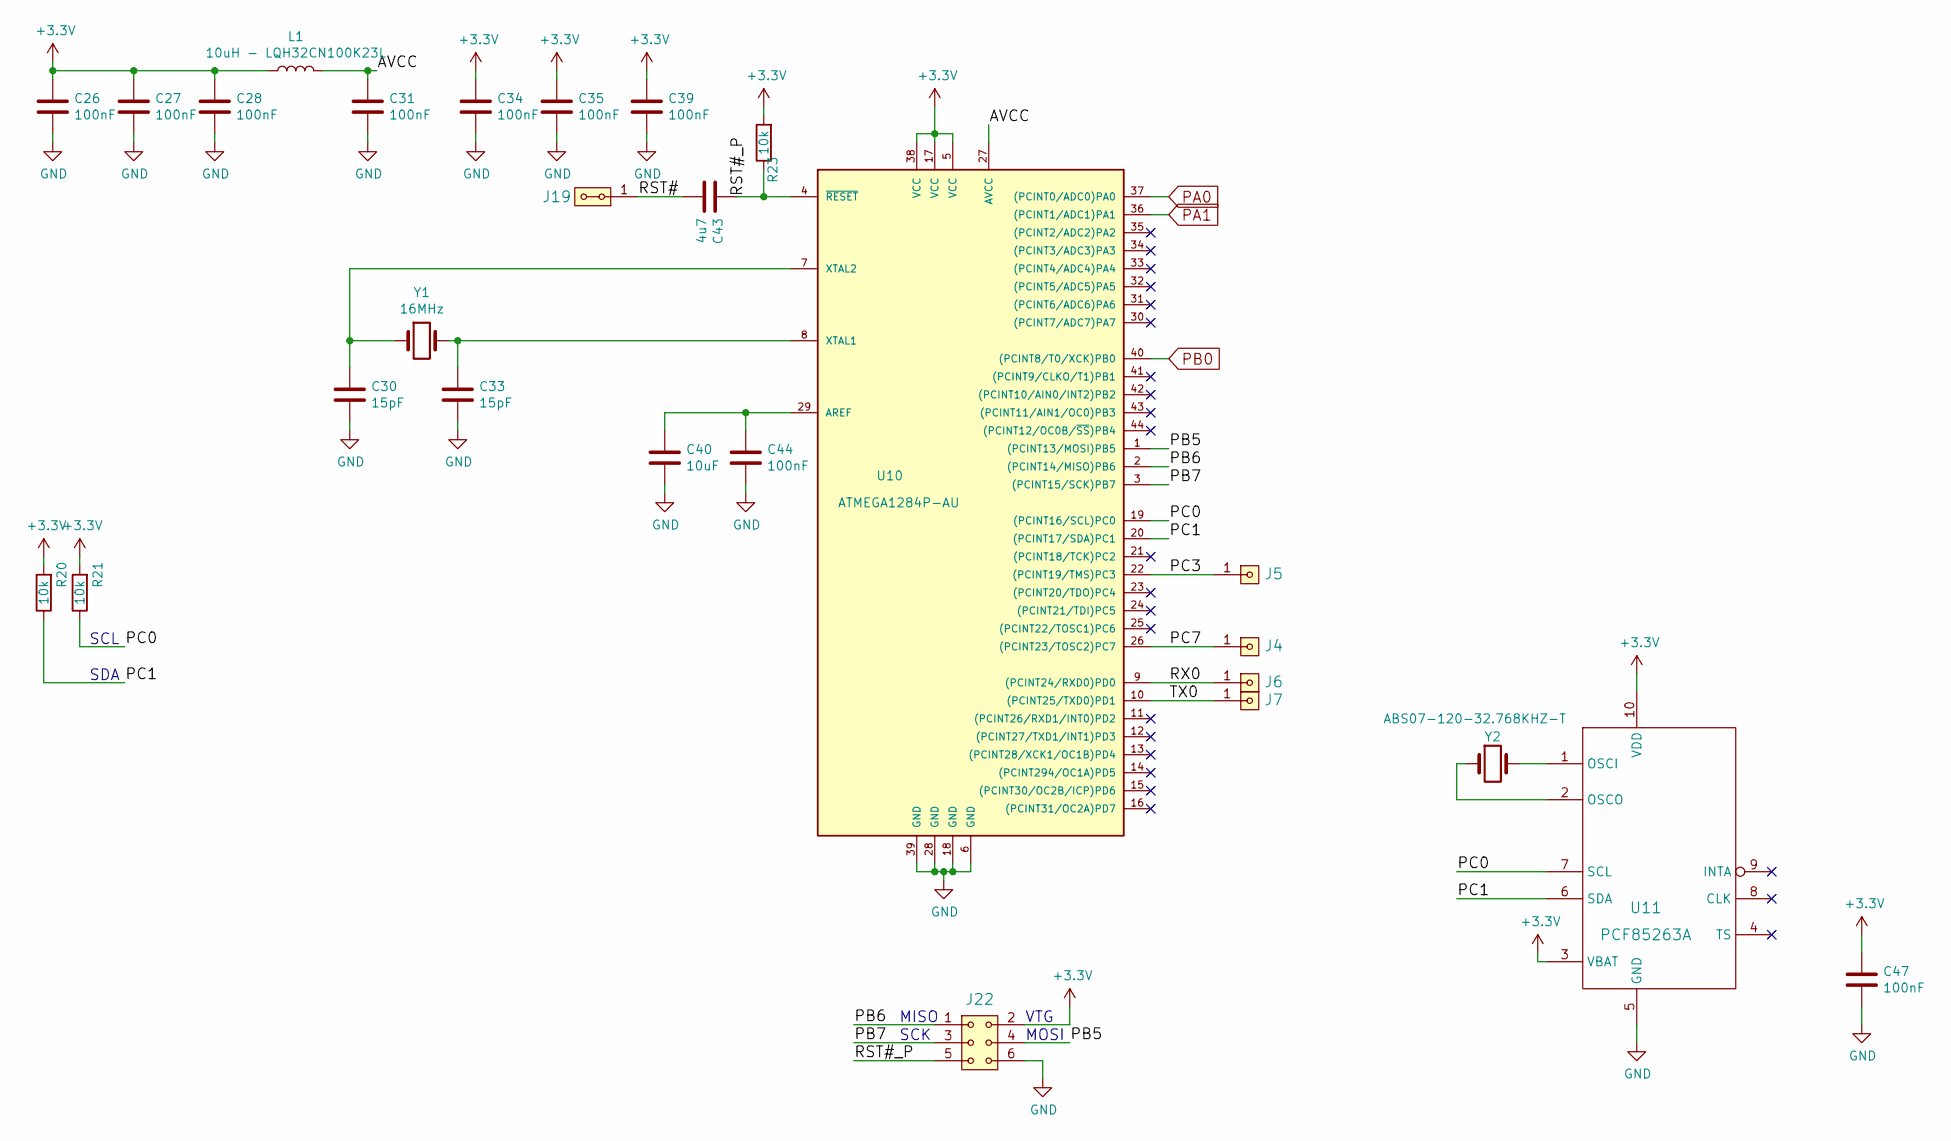
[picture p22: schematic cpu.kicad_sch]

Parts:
C26, C27, C28, C31, C34, C35, C39, C44, C47: 100nF; SMD-0805
C30, C33: 15pF; SMD-0805
C40: 10uF; SMD-0805
C43: 4u7; SMD-0805
J4, J5, J6, J7: HEADER_1x01; Straight_1x01
J19: HEADER_2x01_PARALLEL; Straight_2x01
J22: HEADER_2x03; SMD_2x03
L1: 10uH - LQH32CN100K23L; SMD-1210
R20, R21, R23: 10k; SMD-0805
U10: ATMEGA1284P-AU; TQFP-44_10x10mm_P0.8mm
U11: PCF85263A; TSSOP-10_3x3mm_Pitch0.5mm
Y1: 16MHz; Crystal_HC49-4H_Vertical
Y2: ABS07-120-32.768KHZ-T; ABS07

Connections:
+3V3: C26.1, C27.1, C28.1, C34.1, C35.1, C39.1, C47.1, J22.2, L1.1, R20.2, R21.2, R23.2, U10.5 (VCC), U10.17 (VCC), U10.38 (VCC), U11.3 (VBAT), U11.10 (VDD); also elsewhere on the board
/cpu/AVCC: C31.1, L1.2, U10.27 (AVCC)
/cpu/PB5: J22.4, U10.1 ((PCINT13/MOSI)PB5)
/cpu/PB6: J22.1, U10.2 ((PCINT14/MISO)PB6)
/cpu/PB7: J22.3, U10.3 ((PCINT15/SCK)PB7)
/cpu/PC0: R21.1, U10.19 ((PCINT16/SCL)PC0), U11.7 (SCL)
/cpu/PC1: R20.1, U10.20 ((PCINT17/SDA)PC1), U11.6 (SDA)
/cpu/PC3: J5.1, U10.22 ((PCINT19/TMS)PC3)
/cpu/PC7: J4.1, U10.26 ((PCINT23/TOSC2)PC7)
/cpu/RST#: C43.2, J19.1, J19.2
/cpu/RST#_P: C43.1, J22.5, R23.1, U10.4 (~RESET)
/cpu/RX0: J6.1, U10.9 ((PCINT24/RXD0)PD0)
/cpu/TX0: J7.1, U10.10 ((PCINT25/TXD0)PD1)
GND: C26.2, C27.2, C28.2, C30.2, C31.2, C33.2, C34.2, C35.2, C39.2, C40.2, C44.2, C47.2, J22.6, U10.6 (GND), U10.18 (GND), U10.28 (GND), U10.39 (GND), U11.5 (GND); also elsewhere on the board
unnamed: C30.1, U10.7 (XTAL2), Y1.1
unnamed: C33.1, U10.8 (XTAL1), Y1.2
unnamed: C40.1, C44.1, U10.29 (AREF)
unnamed: U11.1 (OSCI), Y2.2
unnamed: U11.2 (OSCO), Y2.1
PA0: U10.37 ((PCINT0/ADC0)PA0); also elsewhere on the board
PA1: U10.36 ((PCINT1/ADC1)PA1); also elsewhere on the board
PB0: U10.40 ((PCINT8/T0/XCK)PB0); also elsewhere on the board

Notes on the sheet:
MISO
MOSI
VTG
SCL
SCK
SDA

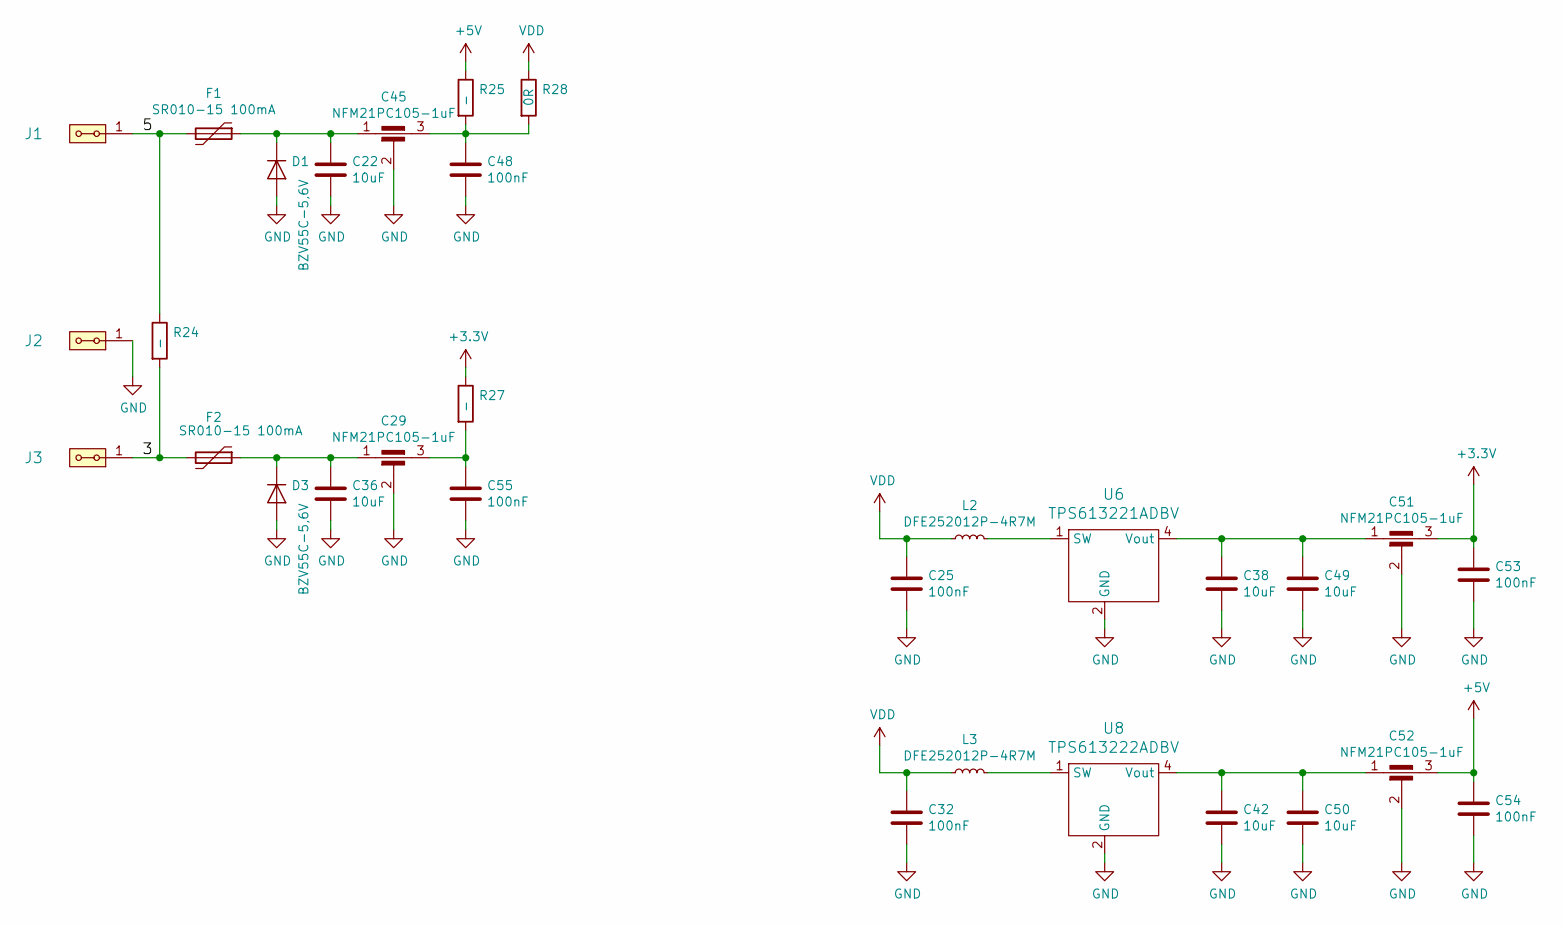
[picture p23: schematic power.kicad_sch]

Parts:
C22, C36, C38, C42, C49, C50: 10uF; SMD-0805
C25, C32, C48, C53, C54, C55: 100nF; SMD-0805
C29, C45, C51, C52: NFM21PC105-1uF; FIR1
D1, D3: BZV55C-5,6V; D_MiniMELF
F1, F2: SR010-15 100mA; SMD-0805
J1, J2, J3: HEADER_2x01_PARALLEL; Straight_1x02
L2, L3: DFE252012P-4R7M; R_0805_2012Metric_Pad1.15x1.40mm_HandSolder
R24, R25, R27: -; SMD-0805
R28: 0R; SMD-0805
U6: TPS613221ADBV; SOT-23-5
U8: TPS613222ADBV; SOT-23-5

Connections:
+3V3: C51.3, C53.1, R27.1; also elsewhere on the board
+5V: C52.3, C54.1, R25.1; also elsewhere on the board
/power/3: F2.2, J3.1, J3.2, R24.2
/power/5: F1.2, J1.1, J1.2, R24.1
GND: C22.2, C25.2, C29.2, C32.2, C36.2, C38.2, C42.2, C45.2, C48.2, C49.2, C50.2, C51.2, C52.2, C53.2, C54.2, C55.2, D1.2 (A), D3.2 (A), J2.1, J2.2, U6.2 (GND), U8.2 (GND); also elsewhere on the board
unnamed: C22.1, C45.1, D1.1 (K), F1.1
unnamed: C29.1, C36.1, D3.1 (K), F2.1
unnamed: C29.3, C55.1, R27.2
unnamed: C38.1, C49.1, C51.1, U6.4 (Vout)
unnamed: C42.1, C50.1, C52.1, U8.4 (Vout)
unnamed: C45.3, C48.1, R25.2, R28.2
unnamed: L2.2, U6.1 (SW)
unnamed: L3.2, U8.1 (SW)
VDD: C25.1, C32.1, L2.1, L3.1, R28.1

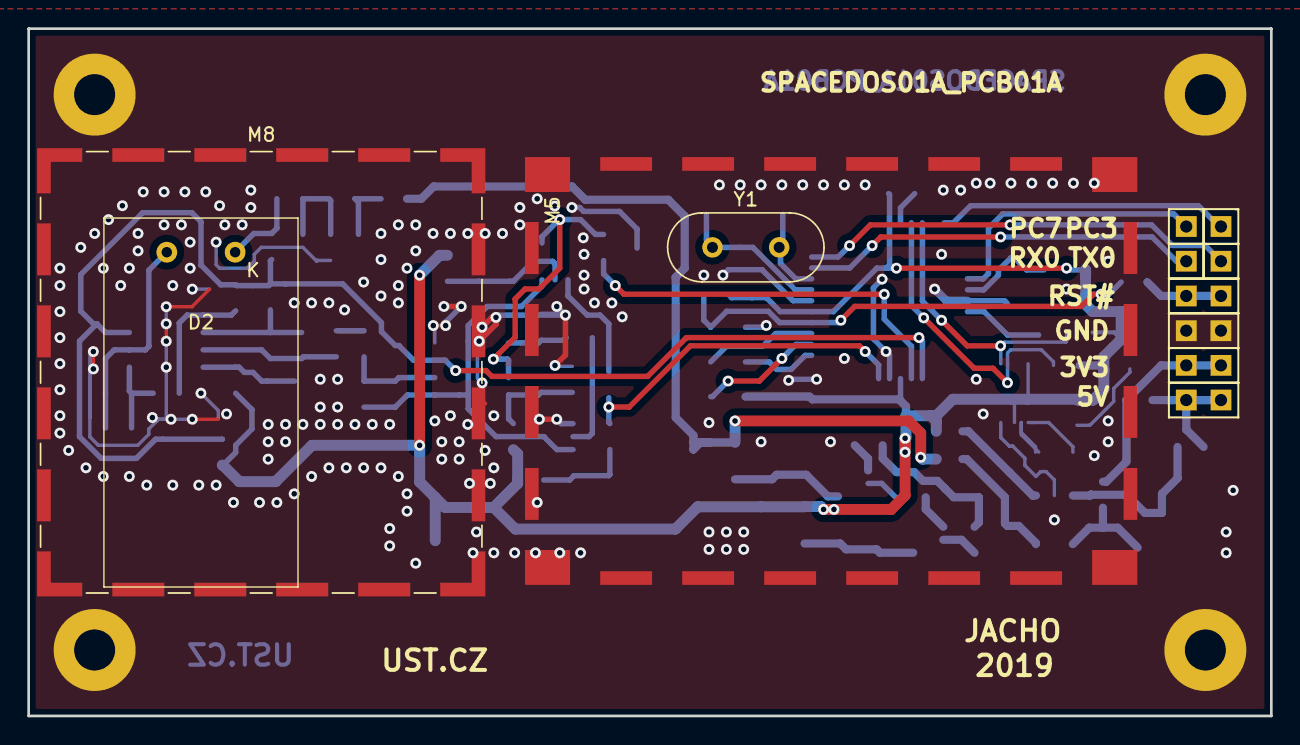
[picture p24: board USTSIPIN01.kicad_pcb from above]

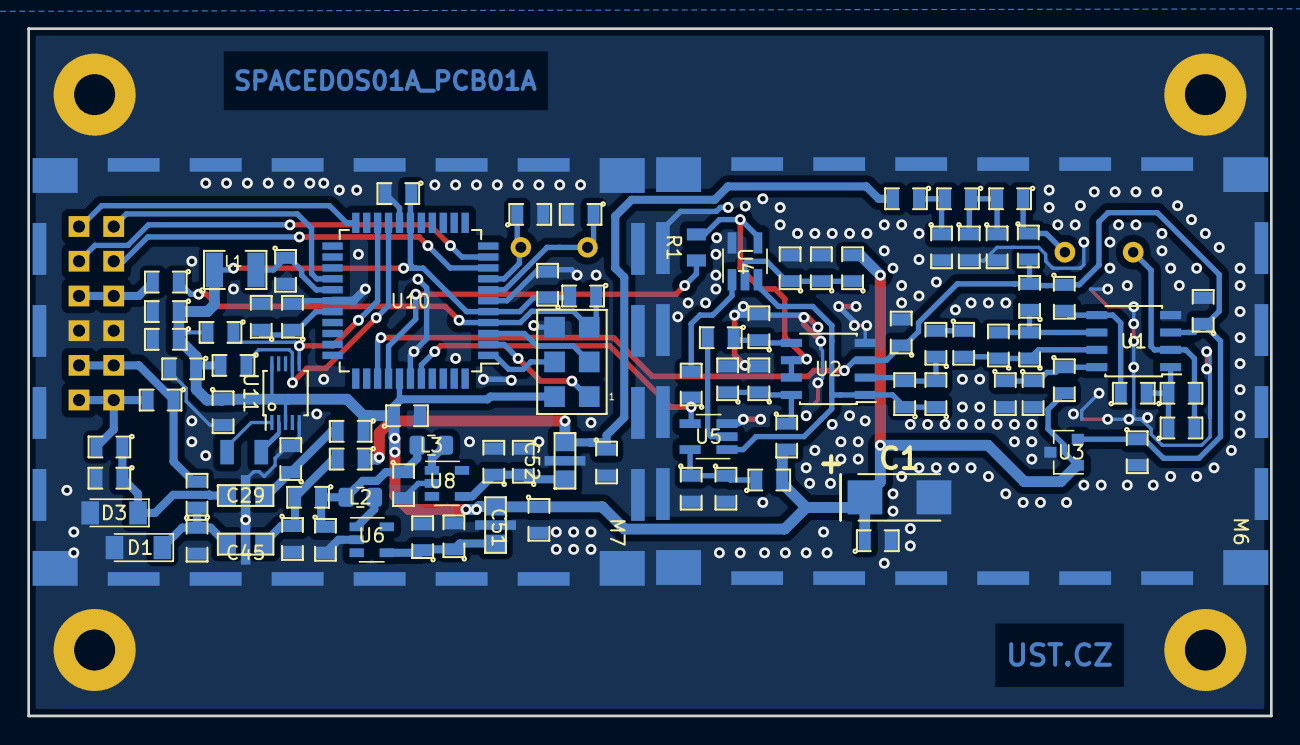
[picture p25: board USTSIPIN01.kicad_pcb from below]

Board: 2 copper layers, 90.9 x 50.3 mm, 111 parts (95 on the bottom side), 53 nets.

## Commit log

2022-04-16 Clean repository, become independent USTSIPIN01
    [SPACEDOS01A_PCB01A.csv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]
2022-04-16 Update actions products
    [USTSIPIN01-B_Cu.dxf, USTSIPIN01-B_Fab.dxf, USTSIPIN01-B_Mask.dxf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]
